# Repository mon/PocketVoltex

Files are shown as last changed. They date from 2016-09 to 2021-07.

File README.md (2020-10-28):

# Pocket Voltex

A tiny controller for K-Shoot MANIA/Sound Voltex or other similar games

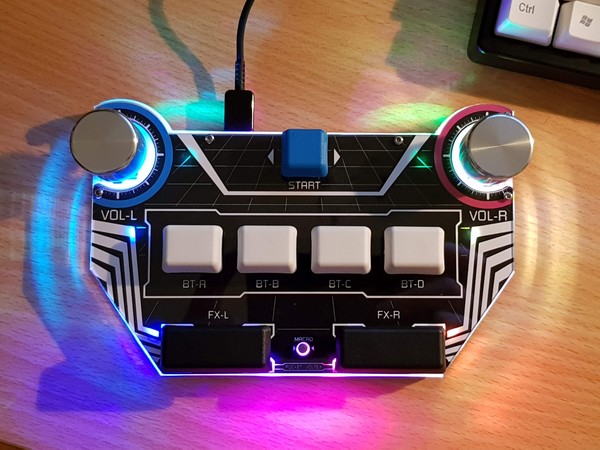
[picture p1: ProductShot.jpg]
Pocket Voltex


## Project status
There is a major revision coming sometime 2021 but I estimate requires 50+ hours
to complete design. It will significantly improve manufacturing efficiency and hopefully
allow me to sell controllers while working full-time.

Please don't hold your breath on a timely release, but I have not forgotten this
project.

## Documentation
[DIY Kit assembly](Docs/Assembly.md)  
[(Old version)DIY Kit assembly](Docs/Assembly_old.md)

[Controller configuration](Docs/Configuration.md)

## Features
* Gateron mechanical switches
* Rock solid Bourns encoders with hardware smoothing
* 8 RGB LEDs
* Beautiful laser cut acrylic case
* Custom aluminium knobs by DJ Dao
* Acts as a gamepad or keyboard/mouse (KSM)
* HID Lighting support
* Configurable card/pin macro key
* Chrome configurator
* No drivers required!

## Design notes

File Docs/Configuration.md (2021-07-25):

# Configuration

Configure your controller with the web app at:
https://mon.im/sdvx/config/

You will need Chrome 57+. You must be using SSL (https, not http).
You *might* also need to go to chrome://flags and enable
"Experimental Web Platform features". This step will not be required by
June/July, as the WebUSB feature will be shipping in Chrome 60.

If you are using b\*\*\*\*\*tools, configure as normal.
For fast configuration of the HID lighting, download and run [this exe](https://github.com/mon/PocketVoltex/raw/master/Software/HidLights.exe)
while config.exe is open and the controller is connected.

## KShootMania configuration
I recommend using the mouse+keyboard mode, as I have noticed slight jitter when using joystick mode - it appears to be caused when the knob rolls over from its maximum value to its minimum value. This also lets you bind START to the enter key, which lets you begin songs with the controller.

However, if you would like to use gamepad mode, simply bind the keys as normal (page 3 of the input selection) and select `Analog X/Y` as the knob input. I find sensitivity at 100 works best.

## NetworkError: Unable to claim interface.
This seems to be caused by broken drivers. Give Zadig a try!
- Download and run [Zadig](http://zadig.akeo.ie/)
- Click Options -> List All Devices
- Select 'Pocket Voltex Config' in the list
- Select WinUSB and click "Replace Driver"
- Config should now work!

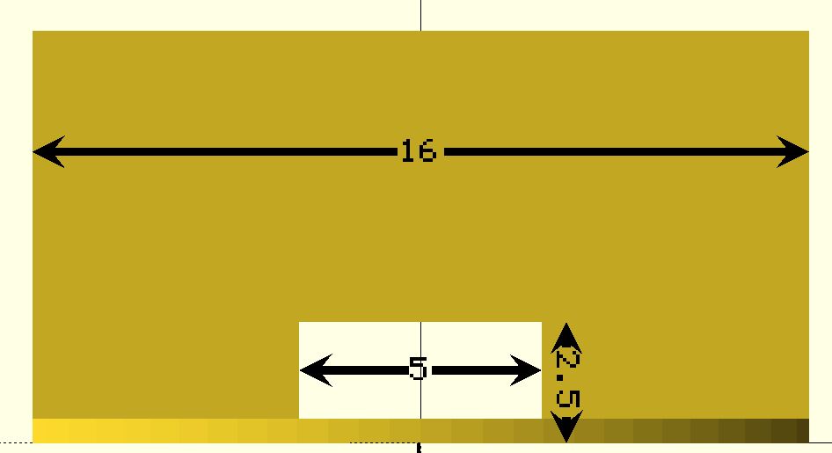
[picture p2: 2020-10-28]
Hardware/Encoder-holder/side.JPG

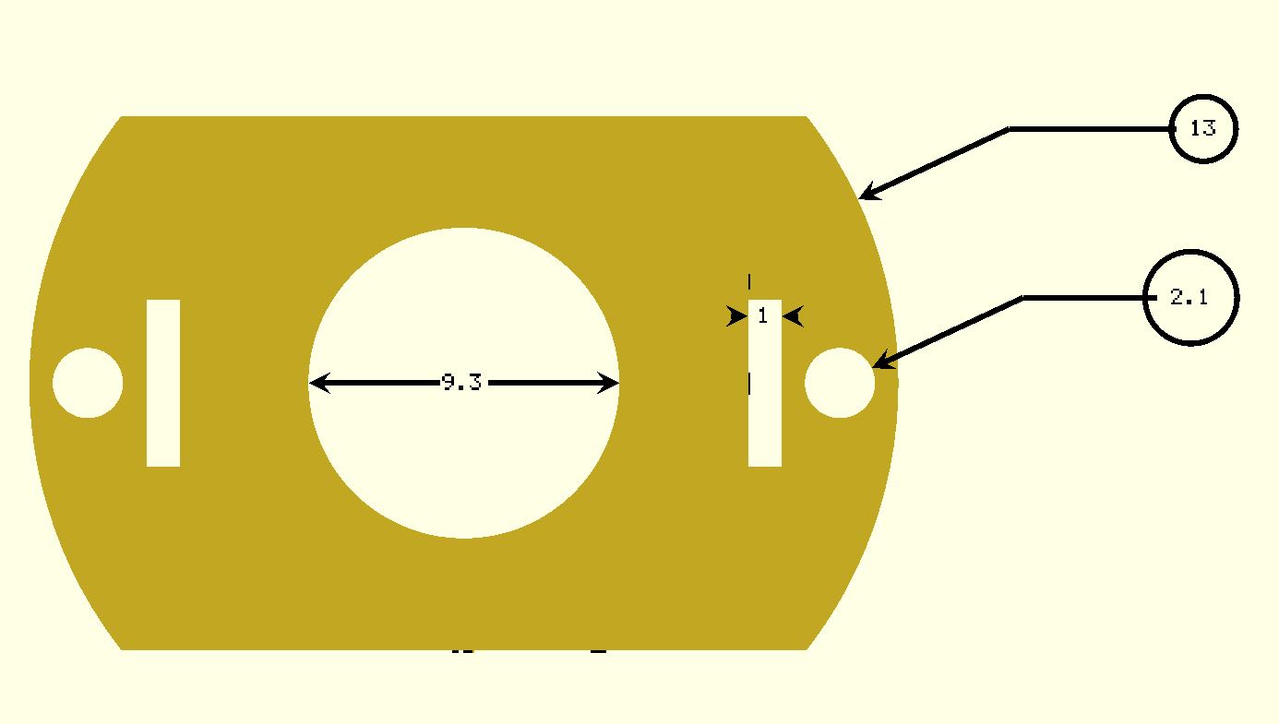
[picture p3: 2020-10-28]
Hardware/Encoder-holder/top.JPG

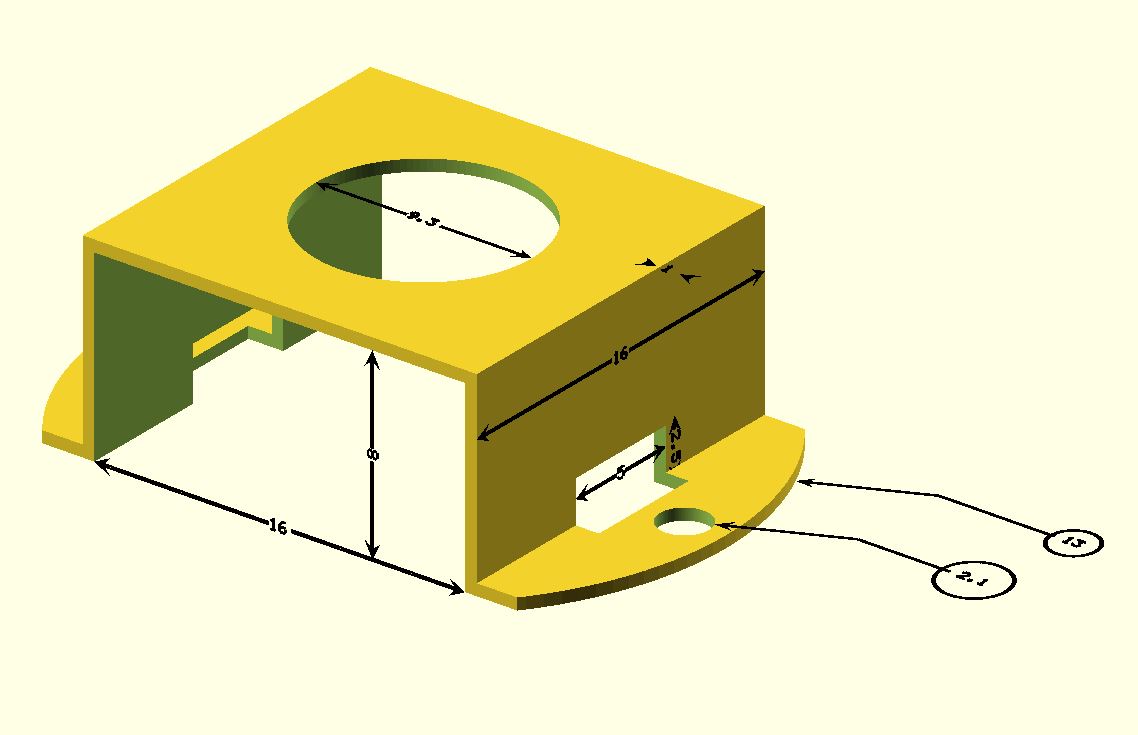
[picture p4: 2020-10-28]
Hardware/Encoder-holder/profile.JPG

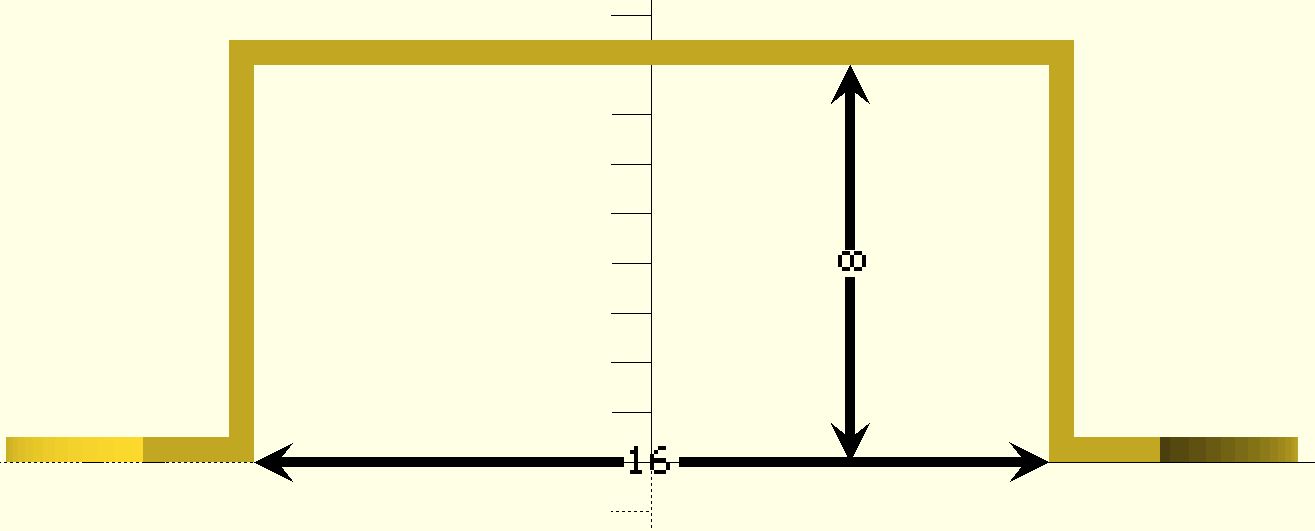
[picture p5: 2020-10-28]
Hardware/Encoder-holder/front.JPG

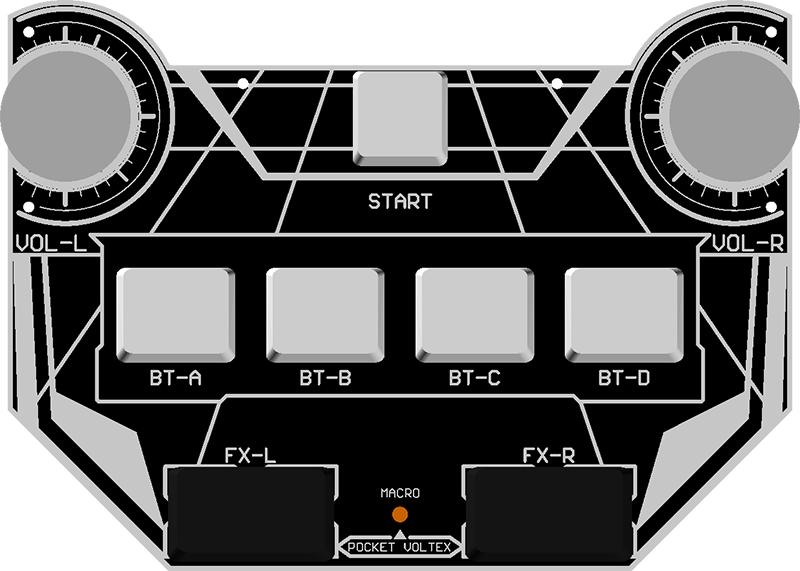
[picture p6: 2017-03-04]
Software/WebConfig/img/r4-topdown-small.png

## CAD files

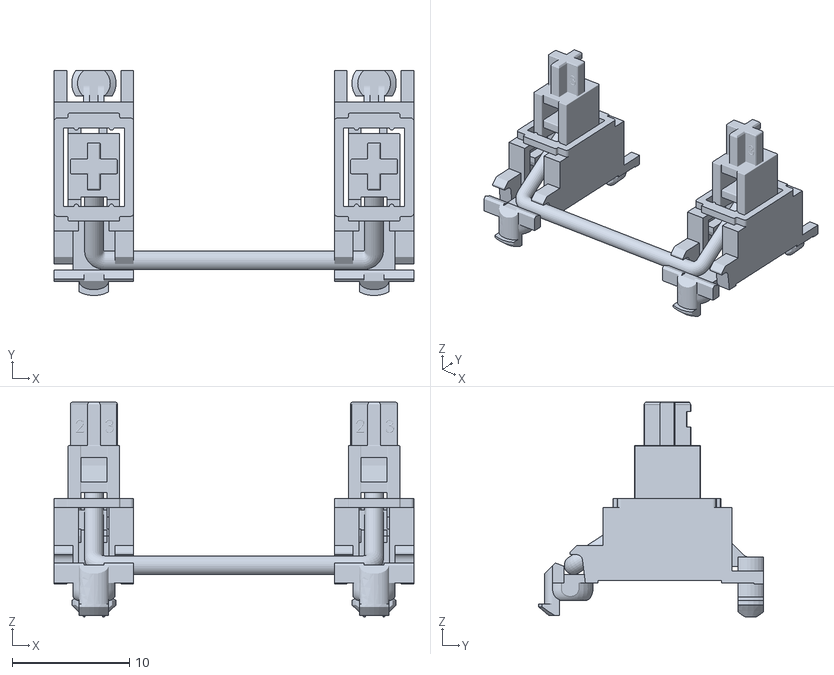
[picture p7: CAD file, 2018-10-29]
Hardware/Case/imports/mx_pcb_stab_open.stl
30.7 x 19.2 x 18.3

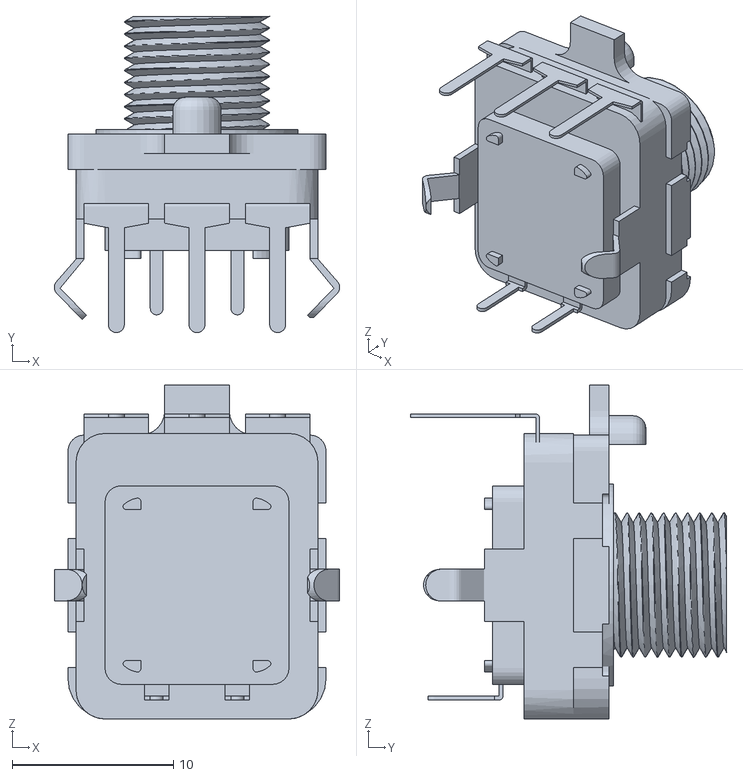
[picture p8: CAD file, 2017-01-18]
Hardware/Encoder-holder/imports/PEC16.stl
17.7 x 19.6 x 20.7

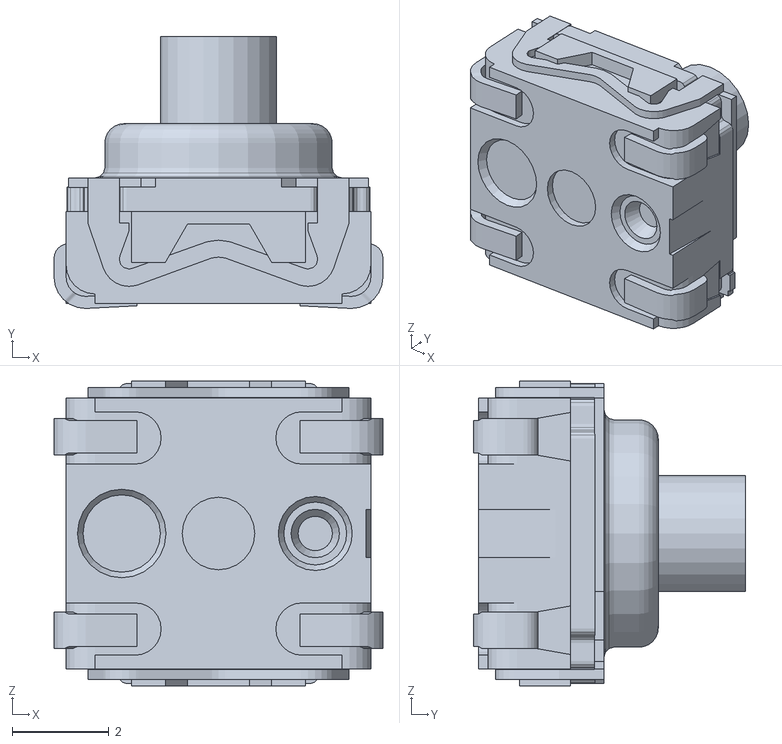
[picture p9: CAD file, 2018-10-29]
Hardware/Case/imports/KSC521J.stl
6.80 x 5.62 x 6.30

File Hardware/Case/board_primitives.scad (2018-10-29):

use <utils.scad>

black = [0.1,0.1,0.1];
blue = [0,0.6,1];
// x, y, keycap width in units, colour, text
bt_map = [[0,0, 1, blue, "START"],
           [-42.862,-37.592, 1.25, "white", "BT-A"],
           [ 42.862,-37.592, 1.25, "white", "BT-D"],
           [-14.287,-37.592, 1.25, "white", "BT-B"],
           [ 14.287,-37.592, 1.25, "white", "BT-C"]];
fx_map = [[-33.3375,-75.692, 2.25, black, "FX-L"],
           [ 33.3375,-75.692, 2.25, black, "FX-R"]];

bolt_map = [[37.4, 6.65],
         [80.5, -15.5],
         [80.5, 16.5],
         [52.732, -82.792]
         ];
encoder_map = [[-73,0.5],
            [ 73,0.5]];
// Not the encoders themselves, but the cutout that surrounds them
encoder_radius = 13;
// and for the board outline
encoder_radius_board = 22.222;

// encoder solder points hit the case unless we cut these out
// x, y, hole size
encoder_holes = [[-8, 0, 4],
                [ 8, 0, 4]];
// the 3 A/B/Gnd connections
// x (mirrored), y, hole size
encoder_hull = [5, -10.5, 3];

// x, y, rotation
led_map = [[47.1, -1.7, 0],
        [65, -30, 90],
        [57, -68, 45],
        [12, -80, 0]];
led_size = [7.5, 6.5];
                
macro_pos = [0,-75.692];
macro_diam = 4.8;

usb_dims = [11, 12];
usb_pos = [-26.52, 10.17];

// So you get a little clear acrylic edge and it looks nice
top_plate_shrink = 1;

fudge = 0.2;

bolt_diam = 2;
bolt_fudge = 0.1;
bolt_size = bolt_diam + bolt_fudge;
spacer_size = bolt_size + 1.7 + fudge; // extra wiggle

module bolts() {
    reflect([1,0,0])
    for(bolt = bolt_map) {
        translate(bolt)
        children();
    }
}

module bolts_external() {
    bolts()
    circle(d=bolt_size);
}

module bolts_internal() {
    bolts()
    circle(d=spacer_size);
}

module switches(map, apply_scaling, colour) {
    for(sw = map) {
        color(colour ? sw[3] : "gray")
        translate([sw.x,sw.y])
        scale([apply_scaling ? sw[2] : 1,1])
        children();
    }
}

module bt(apply_scaling = false, colour = true) {
    switches(bt_map, apply_scaling, colour)
        children();
}

module fx(apply_scaling = false, colour = true) {
    switches(fx_map, apply_scaling, colour)
        children();
}

module switches_all(apply_scaling = false, colour = true) {
    switches(fx_map, apply_scaling, colour)
        children();
    switches(bt_map, apply_scaling, colour)
        children();
}

module encoders() {
    for(enc = encoder_map) {
        translate(enc)
        children();
    }
}

module leds() {
    reflect([1,0,0])
    for(led = led_map) {
        translate([led.x, led.y])
        rotate([0,0,led[2]])
        children();
    }
}

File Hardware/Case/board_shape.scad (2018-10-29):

include <board_primitives.scad>
use <utils.scad>
use <cutouts.scad>

encoder_side_gap = 11;
function board_width() = (abs(encoder_map[0][0]) + encoder_side_gap)*2;

module board_half() {
    // 1mm gap for the important bits
    top_gap = 10.16;
    
    // arbitrary
    height = 96.64;
    angled_xoff = 55;
    
    // calculated
    width = board_width()/2;
    
    // main body
    translate([0, -height + top_gap])
    difference() {
        square([width, height]);
        
        translate([angled_xoff,0])
        rotate([0,0,-35])
        square([width, height]);
    }
    
    // encoder bits
    difference() {
        translate(encoder_map[1])
        circle(r=encoder_radius_board);
        
        translate([width, -height/2])
        square([width, height]);
    }
}

module board() {
    reflect([1,0,0])
    board_half();
}

module top_outline() {
    difference() {
        board();
        encoder_cutouts(smooth = true);
    }
}

board();

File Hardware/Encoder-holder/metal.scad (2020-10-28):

include <imports/dimlines.scad>
use <utils.scad>

$fn = 128;

// 0.2 a little less for tight hold
encoder = [16+0.2, 16, 6.5 - 0.2];
encoder_diam = 26;
side_cut = 0;
side_cut_height = 1.5;
side_cut_flat = 0.5;
hole_cut = 9.3;

material_thick = 0.8;

wing_rounding = 2;
hole_size = 2.1;
hole_clearance = 1.5;
hole_offset = [2.75+0.3,0,0];
wing_length = encoder.x*2; // will be trimmed

DIM_LINE_WIDTH = 0.17;
DIM_FONTSCALE = DIM_LINE_WIDTH * 0.4;

echo(wing_length);

module encoder_model() {
    translate([0,0,5.5])
    rotate([90,0,0])
    import("imports/PEC16.stl");
    
    // Shaft
    encoder_shaft = 6;
    encoder_flat = 4.5;
    translate([0,0,6.5])
    linear_extrude(20)
    intersection() {
        circle(d = encoder_shaft);
        translate([0, (encoder_shaft-encoder_flat)/2])
        square([encoder_shaft, encoder_flat], center = true);
    }
}

module xycube(dims) {
    translate([0,0,dims.z/2])
    cube(dims, center=true);
}

module main_bit() {
    intersection() {
        difference() {
            union() {
                xycube(encoder + [material_thick*2, 0, material_thick]);
                
                //color("green")
                xycube([
                    wing_length*2 + encoder.x + material_thick*2,
                    encoder.y,
                    material_thick
                ]);
            }
            // offsets are for nice f5 render
            translate([0,0,-1])
            xycube(encoder + [0,1,1]);
            
            // cutouts
            translate([0,0,-0.1])
            xycube([
                encoder.x+side_cut_flat*2+material_thick*2,
                side_cut,
                side_cut_height-0.1]);
            cylinder(d=hole_cut, h=encoder.z*2);
            
            screw_off = [
                hole_offset.x + encoder.x/2 - 0.2,
                hole_offset.y,
                0   
            ];
            echo("Screw offset from center", screw_off);
            // screws
            reflect([1,0,0])
            reflect([0,1,0])
            translate(screw_off + [0,0,-0.1])
            cylinder(d = hole_size, h = material_thick*2);
            
            
            reflect([1,0,0])
            reflect([0,1,0])
            translate(screw_off + [0,0,material_thick])
            #cylinder(d = 3.8, h = material_thick*2);
        }
        
        cylinder(d = encoder_diam, h = encoder.z*2);
    }
}

module dims() {
    translate([-encoder.x/2,-encoder.y/2,0])
    rotate([90,0,0])
    dimensions(encoder.x);
    
    translate([encoder.x/4,-encoder.y/2,encoder.z])
    rotate([90,90,0])
    dimensions(encoder.z);
    
    translate([encoder.x/2+material_thick,-encoder.y/2,6])
    rotate([90,0,90])
    dimensions(encoder.y);
    
    translate([encoder.x/2+material_thick,-side_cut/2,1.5])
    rotate([90,0,90])
    dimensions(side_cut);
    
    translate([encoder.x/2+material_thick,side_cut/2+0.5,side_cut_height])
    rotate([90,90,90])
    dimensions(side_cut_height);
    
    translate([-hole_cut/2,0,encoder.z+material_thick])
    dimensions(hole_cut);
    
    leader_line(25, encoder_diam/2, 5, 5, text = str(encoder_diam), do_circle=true);
    
    screw_off = [
        hole_offset.x + encoder.x/2 + material_thick,
        hole_offset.y,
        0   
    ];
    
    translate(screw_off + [0,0,material_thick])
    leader_line(25, hole_size/2, 5, 4, text = str(hole_size), do_circle=true);
    
    translate([encoder.x/2 + material_thick,2,material_thick+encoder.z+0.1])
    dimensions(side_cut_flat, loc = DIM_OUTSIDE);
}

//color("gray")
//encoder_model();

//color("black")
//dims();

main_bit();

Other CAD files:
Hardware/Encoder-holder/utils.scad
Hardware/Case/artwork.scad
Hardware/Case/box.scad
Hardware/Case/case.scad
Hardware/Case/cutouts.scad
Hardware/Case/imports/cherry_mx.scad
Hardware/Case/imports/mx_keycap.scad
Hardware/Case/utils.scad
Hardware/Encoder-holder/imports/TextGenerator.scad
Hardware/Encoder-holder/imports/dimlines.scad

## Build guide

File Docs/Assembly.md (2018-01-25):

# Assembly
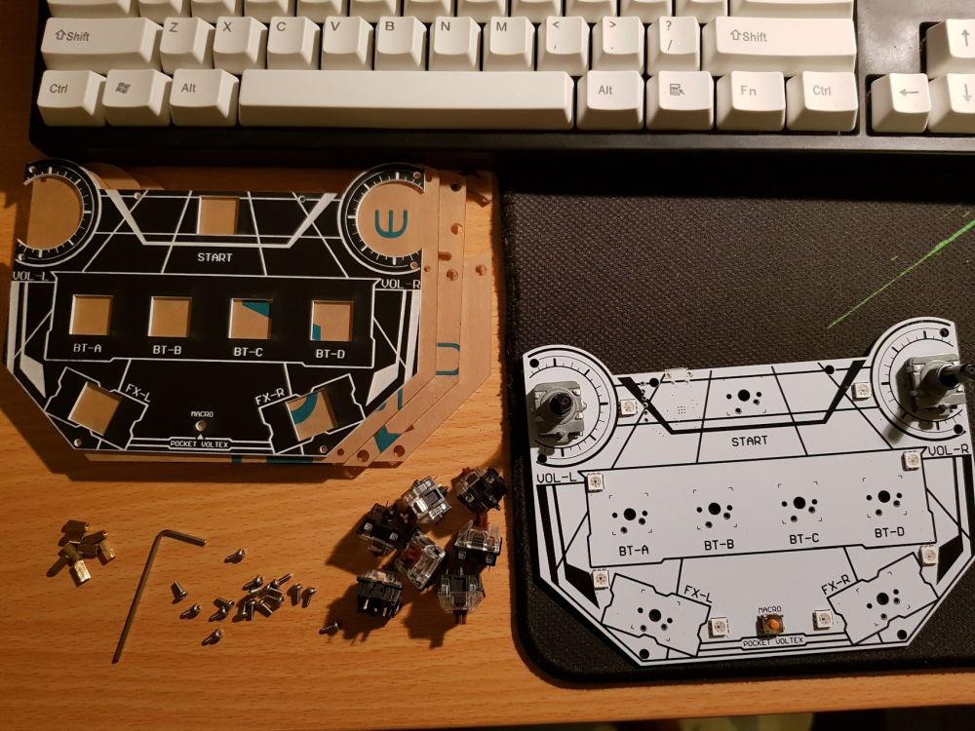
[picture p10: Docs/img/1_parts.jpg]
parts


Run through this guide once before building, ensuring you have all the parts required. You'll also need a soldering iron and solder.

## Acrylic
**STOP NOW!** I *know* it's tempting, but don't peel off the protective backing from all the acrylic yet.
Once it's off, the pieces attract dust, which can make the rear look messy.

**WARNING:** The top 2 plates (those with encoder holes) are fragile and easily snap if dropped. Take care when assembling. Once assembled, they are protected by the rest of the controller and should not break.

Take off the protective backing from the top clear acrylic.
Take your top clear plate and top black plate and place them over the LEDs. Take note of the clear plate - it has engraved edges for optimal lighting. It can be installed with the edges up or down, but they look best when facing up.
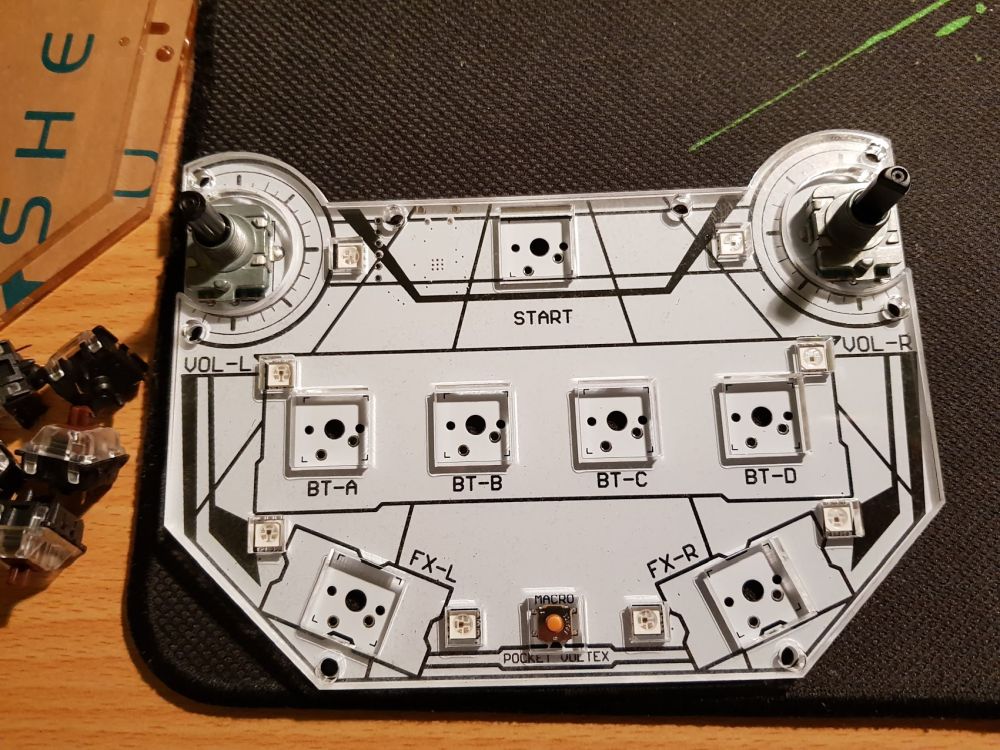
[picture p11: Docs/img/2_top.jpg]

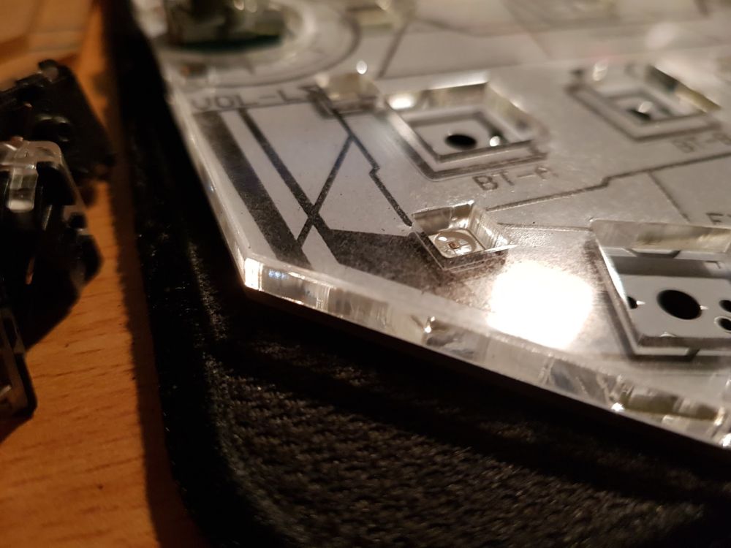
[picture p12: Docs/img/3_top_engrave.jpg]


Use the 1.5mm Allen key provided to screw the board together.
Insert the top 8 bolts and 8 long nuts into the holes provided.
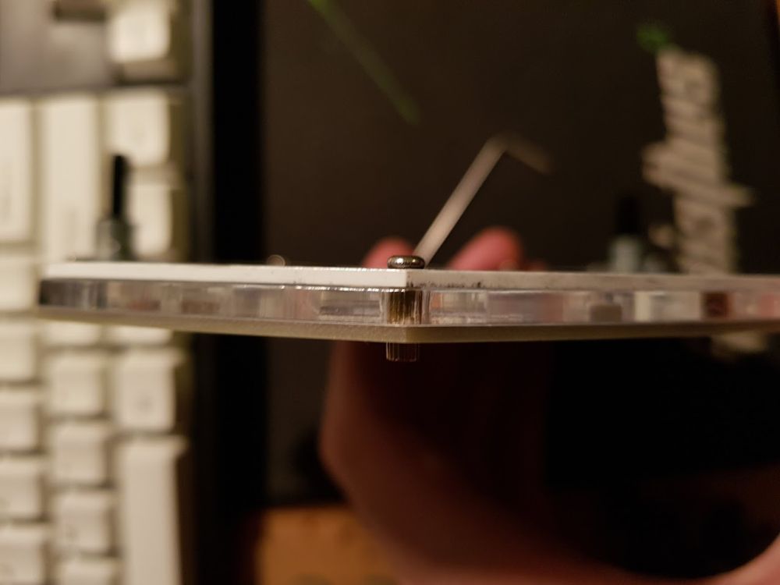
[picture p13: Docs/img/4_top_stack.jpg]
nutsNbolts


## Switches
Insert all your switches, and make sure they are seated properly. They are meant to be a tight fit into the PCB and should be completely flush with the surface.
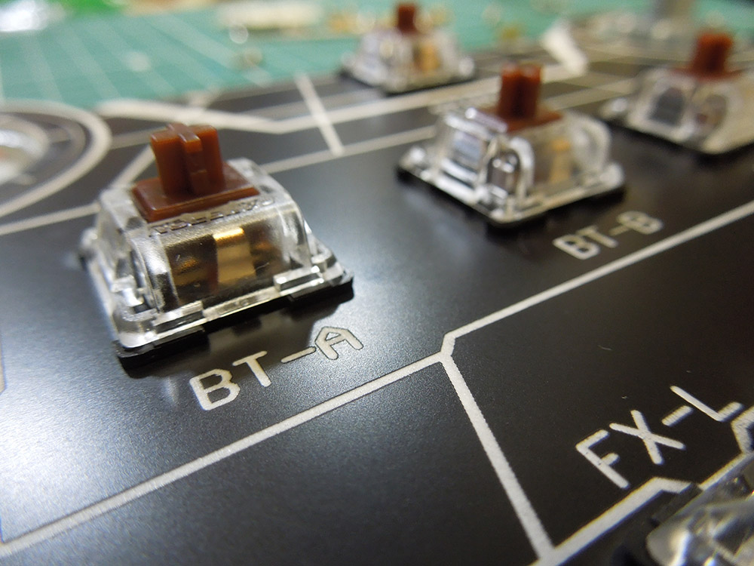
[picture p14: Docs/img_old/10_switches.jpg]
switches


Solder the switches. I solder with the back plate on, with its protective backing. This prevents flux from splashing over your board.
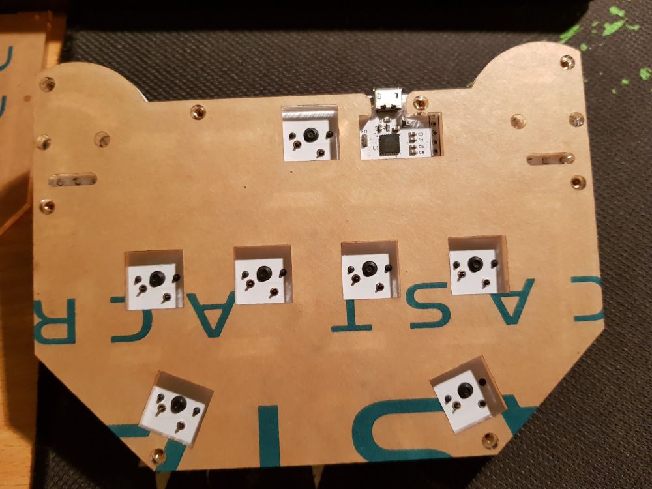
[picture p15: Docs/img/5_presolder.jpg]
protec


## Nuts and bolts
Stack the bottom 2 plates after removing their protective backing and insert the remaining 8 bolts.
Take care to align the cutout over the USB port.
Attach your 6 adhesive rubber feet. You can place these anywhere, but here is where I put them:
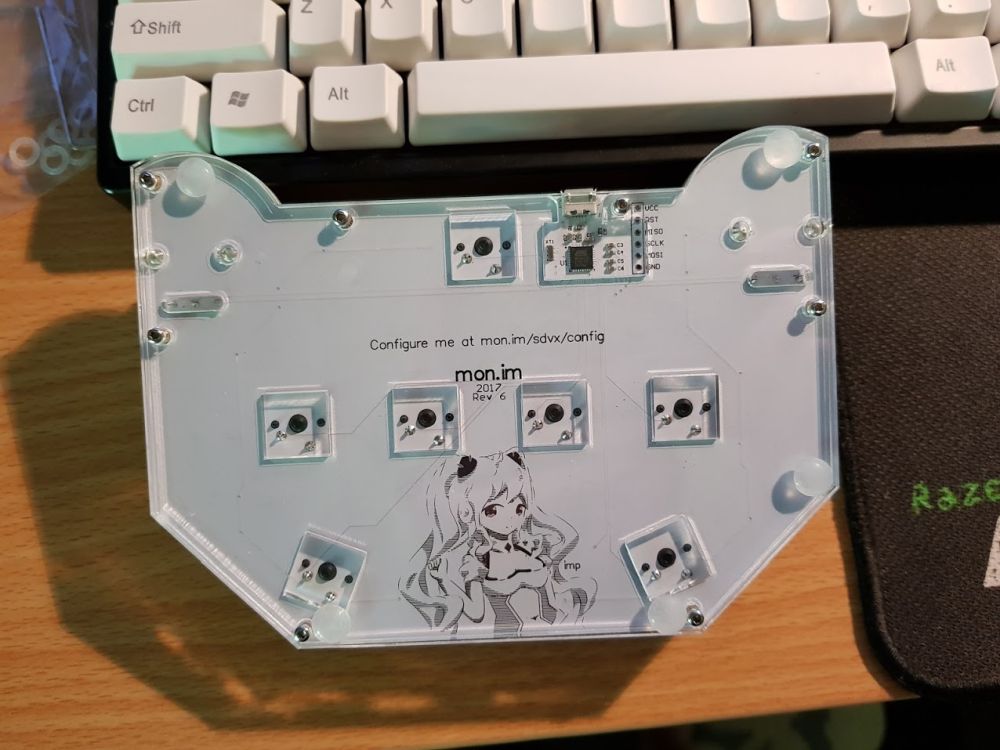
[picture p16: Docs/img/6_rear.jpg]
acrylicDone


# Final touches
Using the Allen key provided, attach the knobs. The encoder shaft is shaped like a D - ensure you tighten the grub screw on the flat part of the D.

*Optional:* Add 7 o-rings to your keycaps to make them quieter.

Install keycaps by simply pushing them onto the switches.

done

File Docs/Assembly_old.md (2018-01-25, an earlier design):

# Assembly
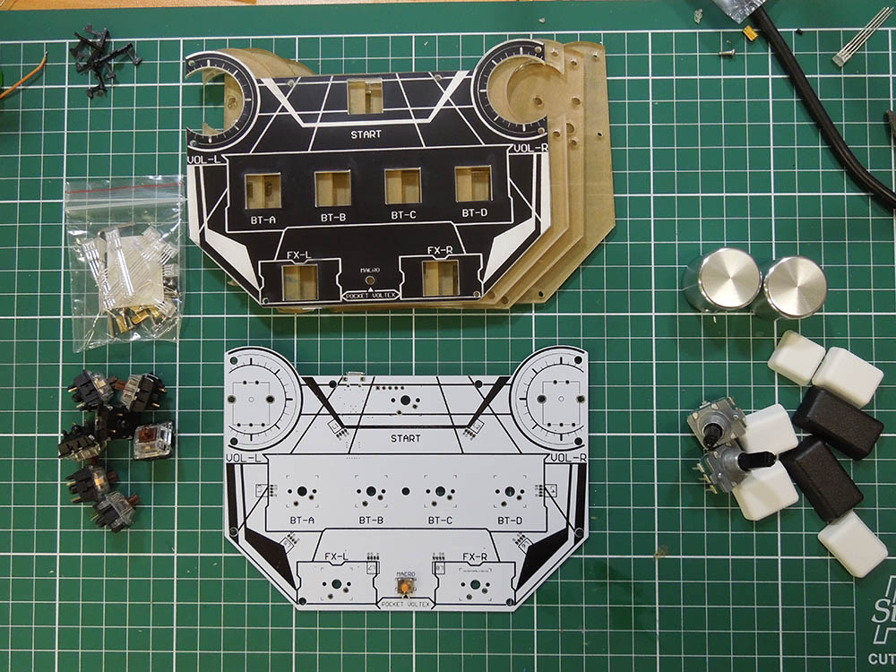
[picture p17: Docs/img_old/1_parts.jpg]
parts


Run through this guide once before building, ensuring you have all the parts required. You'll also need a soldering iron and solder.

## LEDs
First up, the LEDs.

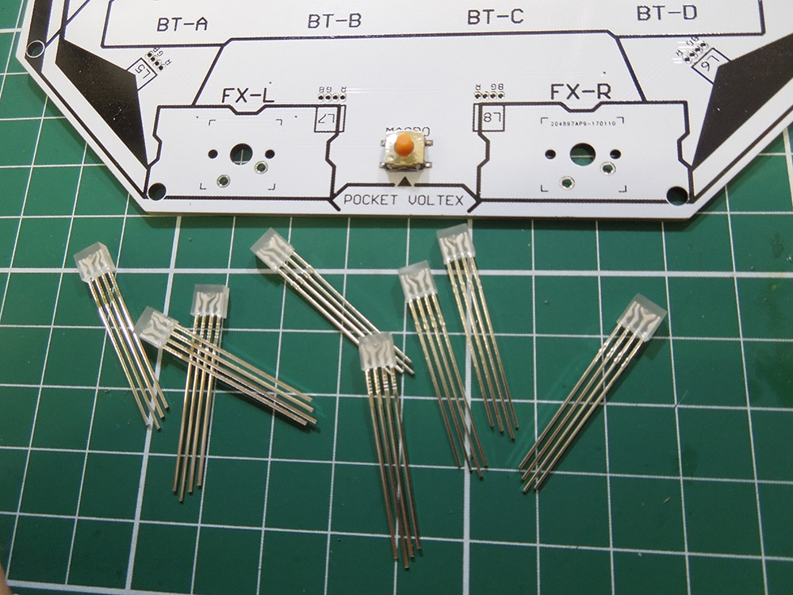
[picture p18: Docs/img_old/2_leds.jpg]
leds


Take note, each LED point on the board has labelled connections for R, G and B. The long leg on the LEDs goes into the unmarked (ground) hole.

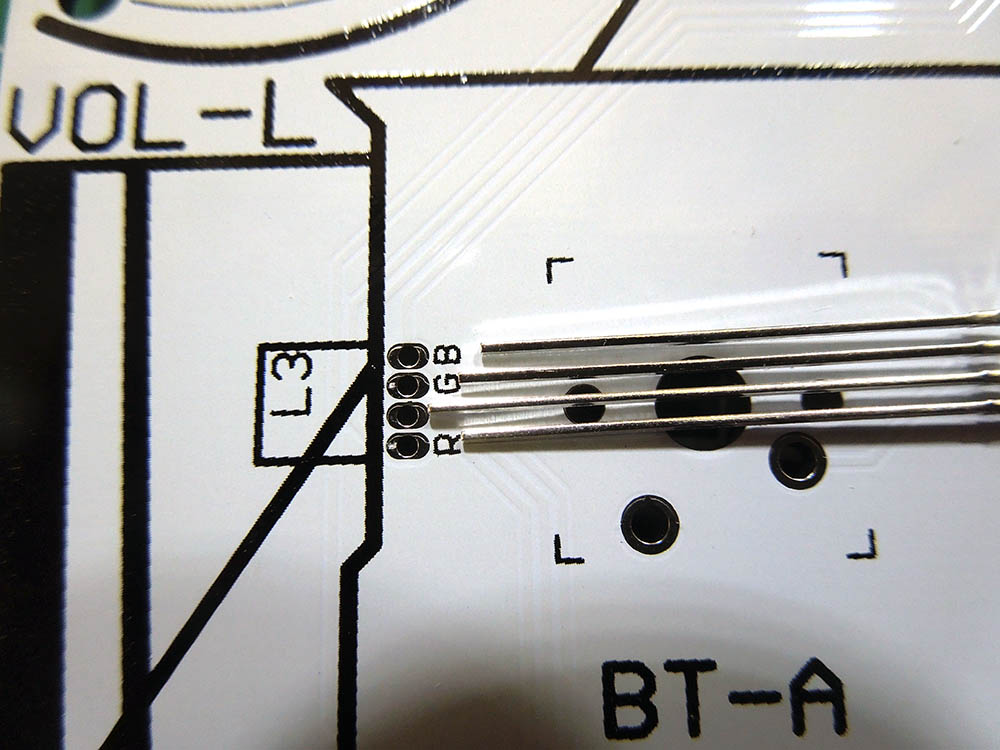
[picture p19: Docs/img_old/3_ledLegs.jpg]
ledLegs


Insert the LEDs roughly to the red line, then bend them over:
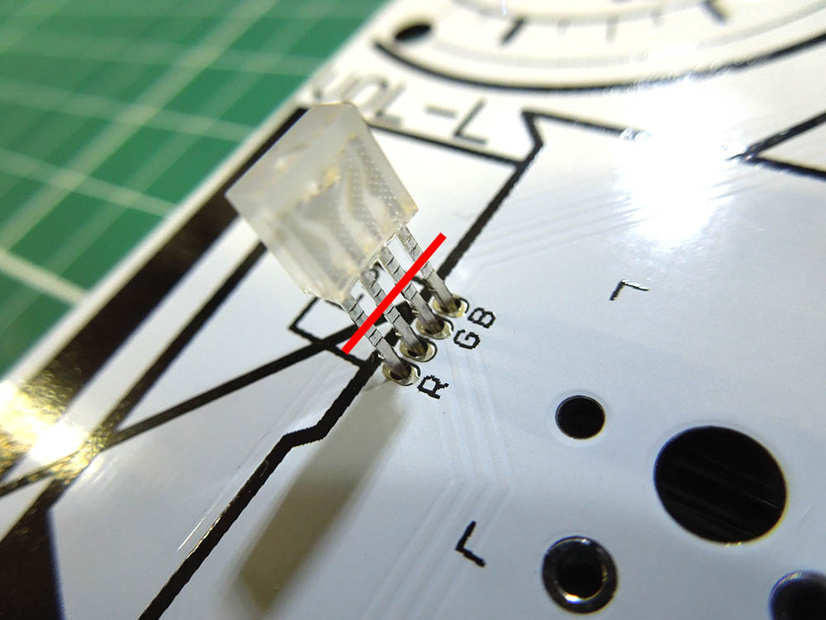
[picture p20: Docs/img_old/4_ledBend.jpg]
ledBend

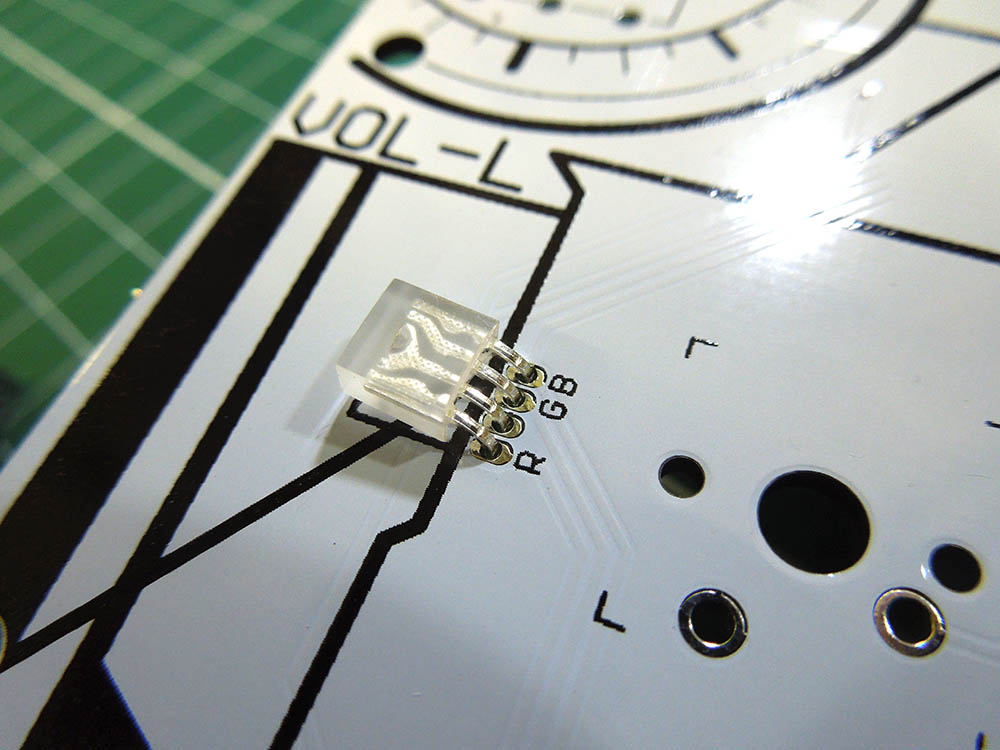
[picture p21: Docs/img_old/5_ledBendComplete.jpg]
ledBendComplete


Work on a slightly raised surface and place the board face down to solder, with the MACRO switch off the edge. This ensures all the LEDs are flush with the board surface.
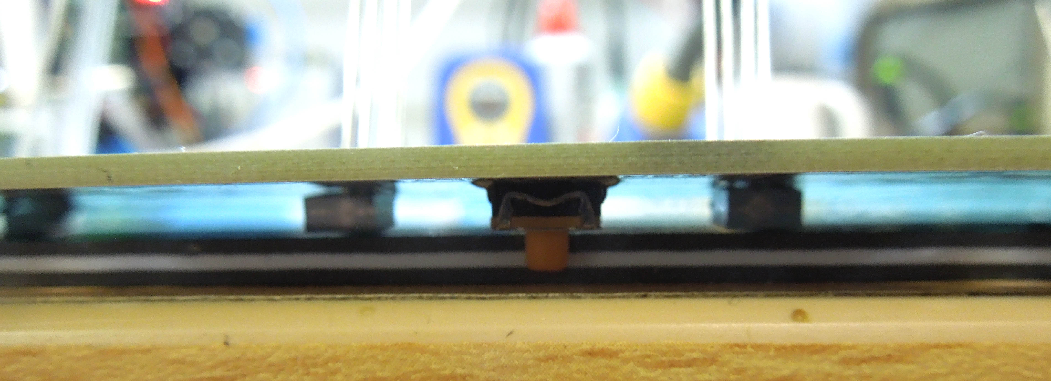
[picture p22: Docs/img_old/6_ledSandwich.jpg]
ledSandwich


I recommend soldering one leg of each LED to keep it in place, then cutting off all the leads. This makes soldering the rest of the connections much easier.

The bend doesn't have to be perfect - the acrylic will diffuse the light.
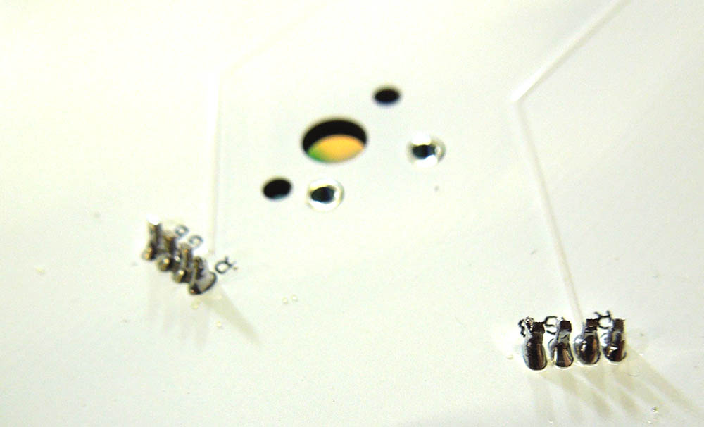
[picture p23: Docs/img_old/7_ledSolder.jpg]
ledSolder


## Encoders
You can solder the encoders now or after you install the switches, but I prefer to do them sooner. Solder one of the small pins to keep it in place then pump lots of solder into the big connecting lugs. These need to take your abuse, so make it a good joint!
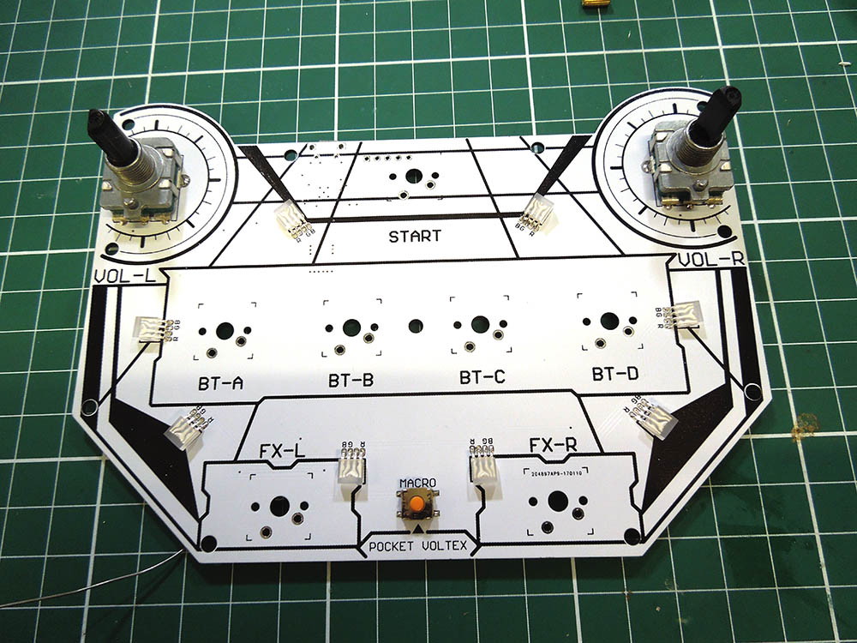
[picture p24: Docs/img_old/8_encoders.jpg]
encoders


## Switches
**STOP NOW!** Have you finished soldering your LEDs? Have you tested them?
Once you have soldered the switches you cannot fix anything without desoldering
them again.

**WARNING:** The top 2 plates (those with encoder holes) are fragile and easily snap if dropped. Take care when assembling. Once assembled, they are protected by the rest of the controller and are much stronger.

Take your top clear plate and top black plate and place them over the LEDs. Take note of the clear plate - it has engraved edges for optimal lighting. It can be installed with the edges up or down, but they look best when facing up.
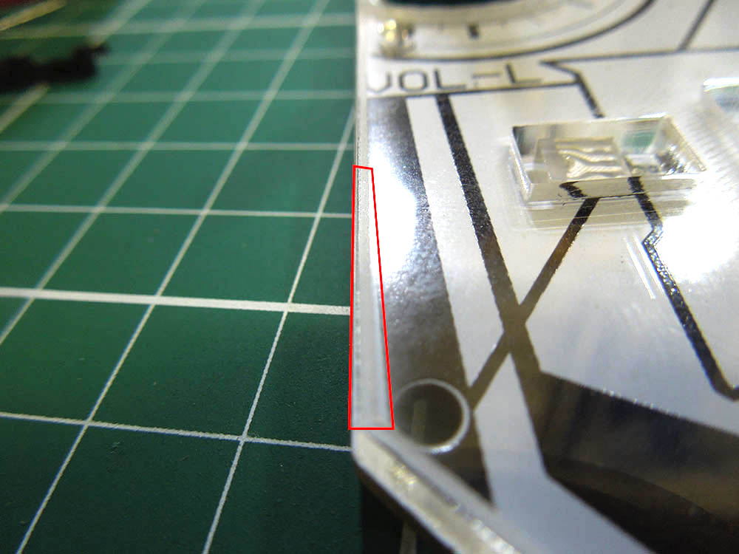
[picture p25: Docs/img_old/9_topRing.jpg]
topRing


Insert all your switches, and make sure they are seated properly. They are meant to be a tight fit into the PCB and should be completely flush with the surface.
switches

## Nuts and bolts
Use the 1.5mm Allen key provided to screw the board together.
Insert the top 8 bolts and 8 long nuts into the holes provided. Take note, there are 3 holes in the PCB that are unused. These nuts can sometimes be a tight fit - you may need to push them into the case with a hard surface.
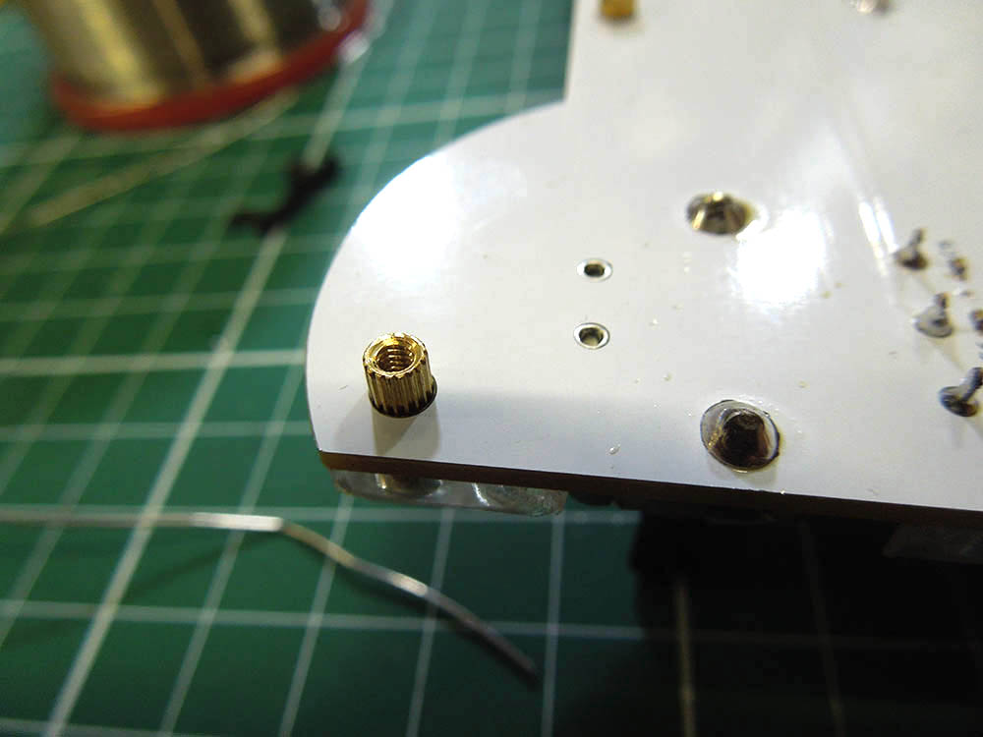
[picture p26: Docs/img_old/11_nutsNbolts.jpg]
nutsNbolts


Stack the bottom 2 plates and insert the remaining 8 bolts. Take care to align the cutout over the USB port. The bolts are a fraction too short, you may need to back off the top bolts by about 2 turns to get the nut close enough.
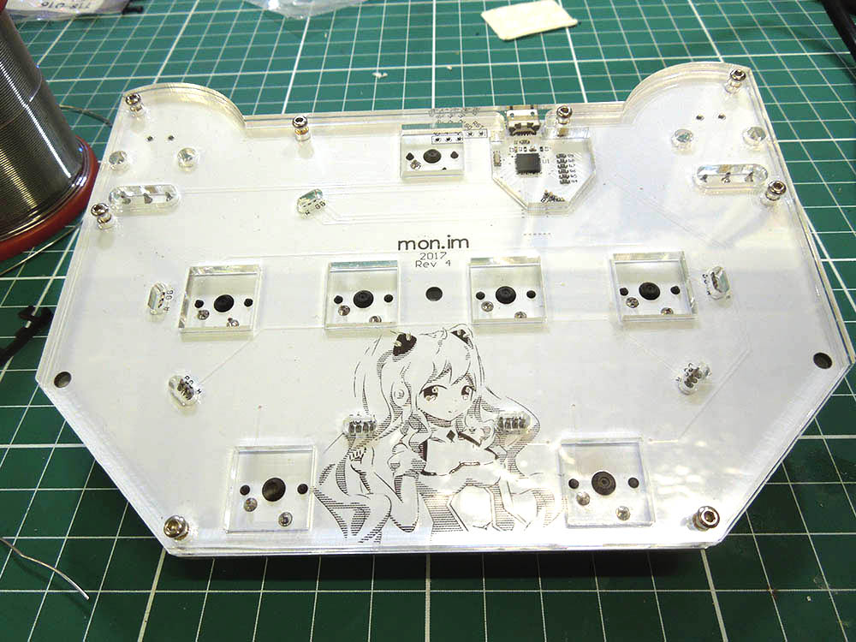
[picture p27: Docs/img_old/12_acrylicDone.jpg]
acrylicDone


## Rubber feet
Attach your 6 adhesive rubber feet. You can place these anywhere, but here is where I put them:
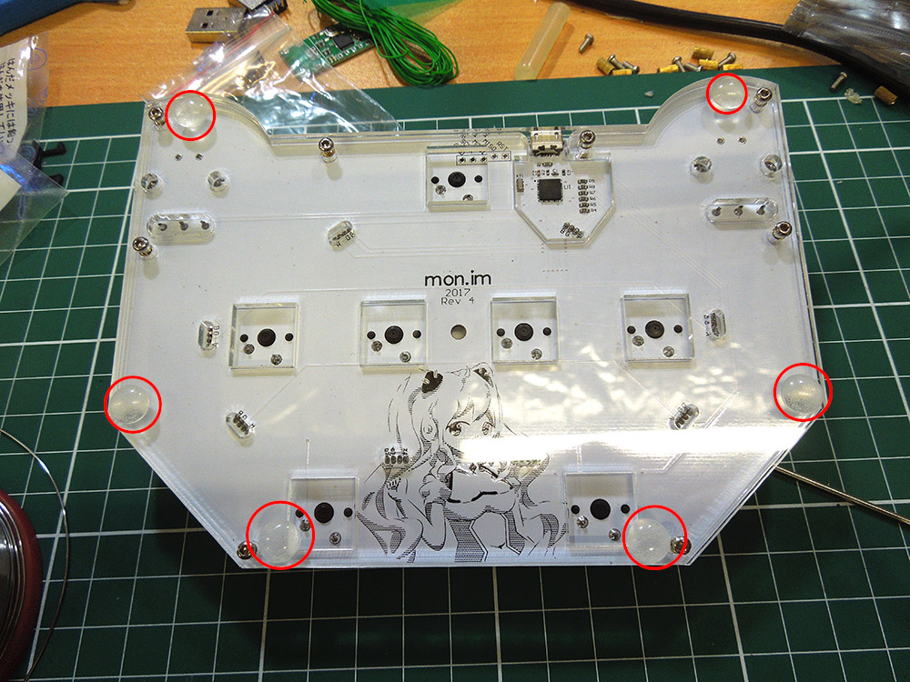
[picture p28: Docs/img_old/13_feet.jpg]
feet


# Final touches
Using the Allen key provided, attach the knobs. The encoder shaft is shaped like a D - ensure you tighten the grub screw on the flat part of the D.

*Optional:* Add 7 o-rings to your keycaps.

Install keycaps by simply pushing them onto the switches.

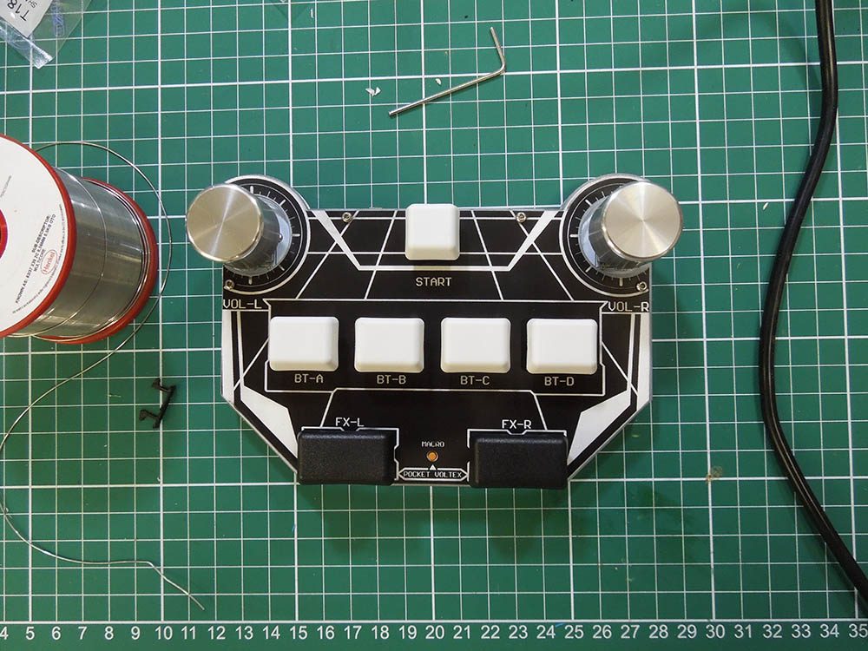
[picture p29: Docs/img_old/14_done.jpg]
done


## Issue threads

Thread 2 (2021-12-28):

PocketVoltex with ProMicro

Katsuyuki-Karasawa, 2021-12-28:
This keyboard is very practical (especially in Japan, where there is a definite demand for it), and since there is an actual store in Japan related to homemade keyboards called Yusha Kobo, we'd really like to see it supported!

mon, 2021-12-29:
I've been to that store! Such a wonderful place.

I'm a little confused as to the request, though. What are you proposing?
- Pocket Voltex with socket/connectors for Pro Micro
- Pocket Voltex that supports using the Arduino Bootloader (atmega32u4 and correct pinout)

I am currently designing a new version that uses the 32u2 (note: u2 not u4, less pins) which can use an arduino core I think, I haven't checked. It will also have a plastic case, so it's taking a bit of time.

I think, for a more DIY friendly Pocket Voltex you might want to look at https://github.com/speedypotato/Pocket-SDVX
It uses a Pro Micro already! And uses a 3D printed case. It's very maker-friendly ^_^

Closed 2022-01-02.

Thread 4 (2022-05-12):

about fireware

HHHHHWTF, 2022-05-12:
When I download LUFA170418 and copy LUFA file folder and run a .bat file name multiflasher from PocketVoltex on Firmware,I get some code:
      0 [main] sh 10300 sync_with_child: child 18804(0x1E0) died before initialization with status code 0xC0000142
    158 [main] sh 10300 sync_with_child: *** child state waiting for longjmp
/usr/bin/sh: fork: Resource temporarily unavailable
      0 [main] sh 9252 sync_with_child: child 1840(0x1EC) died before initialization with status code 0xC0000142
    119 [main] sh 9252 sync_with_child: *** child state waiting for longjmp
/usr/bin/sh: fork: Resource temporarily unavailable
      0 [main] sh 19276 sync_with_child: child 14104(0x1EC) died before initialization with status code 0xC0000142
    223 [main] sh 19276 sync_with_child: *** child state waiting for longjmp
/usr/bin/sh: fork: Resource temporarily unavailable
 [GCC]     : Compiling C file "PocketVoltex.c"
avr-gcc -c -pipe -gdwarf-2 -g2 -mmcu=atmega16u2 -fshort-enums -fno-inline-small-functions -fpack-struct -Wall -fno-strict-aliasing -funsigned-char -funsigned-bitfields -ffunction-sections -I. -DARCH=ARCH_AVR8 -DF_CPU=16000000UL -mrelax -fno-jump-tables -x c -Os -std=gnu99 -Wstrict-prototypes -DUSE_LUFA_CONFIG_HEADER -IConfig/ -Werror  -I. -I../LUFA/.. -DARCH=ARCH_AVR8 -DBOARD=BOARD_USER -DF_USB=16000000UL  -MMD -MP -MF obj/PocketVoltex.d PocketVoltex.c -o obj/PocketVoltex.o
Assembler messages:
Fatal error: can't create obj/PocketVoltex.o: No such file or directory
How can I deal with this problem?

mon, 2022-05-20:
I know you closed this issue, but I just uploaded EVERY manufacturing file:
https://github.com/mon/PocketVoltex/releases/tag/rev7

Good luck! Please email me if you have success.

Closed 2022-05-18.

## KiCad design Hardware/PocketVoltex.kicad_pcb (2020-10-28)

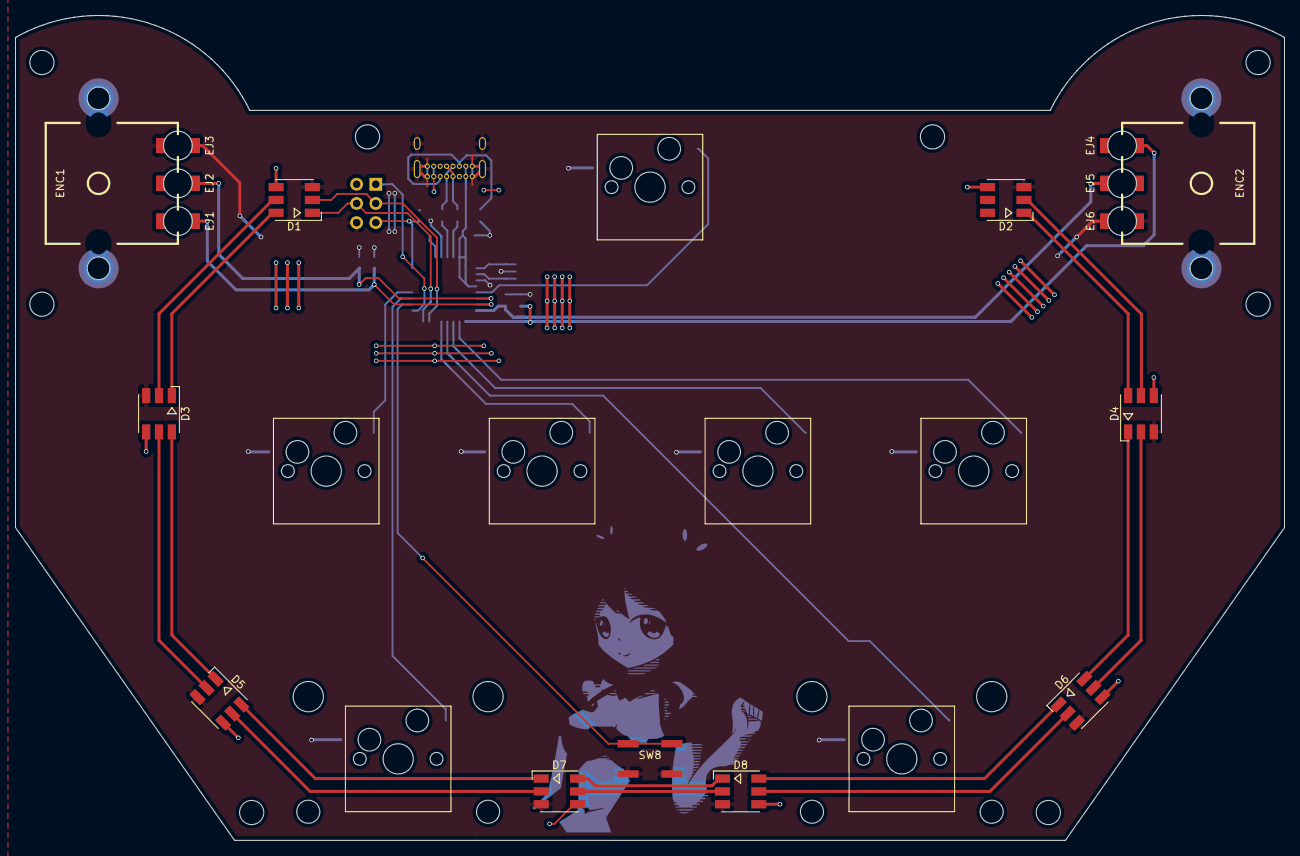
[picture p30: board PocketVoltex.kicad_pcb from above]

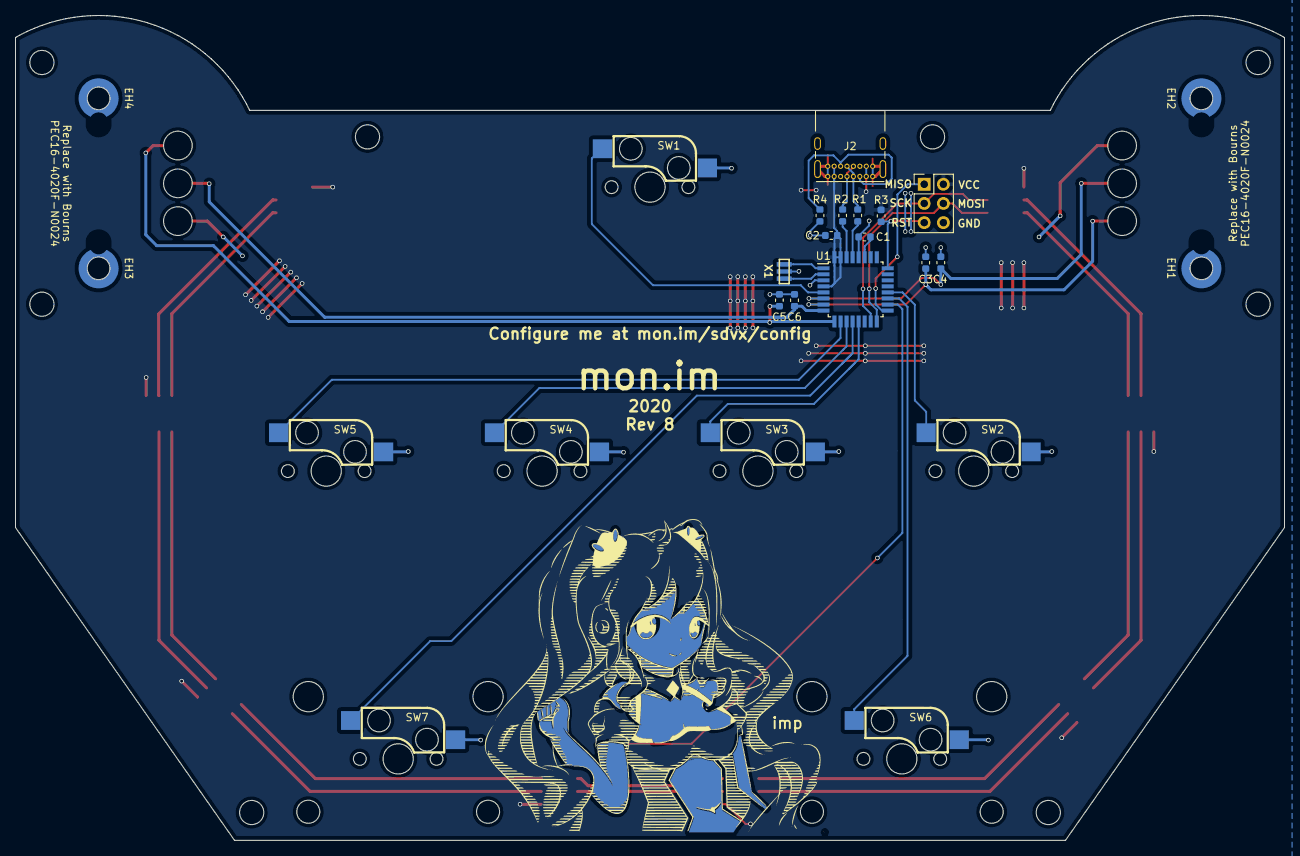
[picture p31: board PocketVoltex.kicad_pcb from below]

Board: 2 copper layers, 168.0 x 109.2 mm, 51 parts (19 on the bottom side), 40 nets.

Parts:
C1: 1uF; C_0603_1608Metric
C2: 10uF; C_0603_1608Metric
C3, C4, C5, C6: 10nF; C_0603_1608Metric
D1, D2, D3, D4, D5, D6, D7, D8: SK9822; LED_SK9822
EH1, EH2, EH3, EH4: Encoder nut; SMD_Standoff_M2_Wurth
EJ1, EJ2, EJ3, EJ4, EJ5, EJ6: Hotswap; Harwin-SMD-Socket-S9091-46R
ENC1: VOL_L; Encoder_Bourns_PEC16_hotswap
ENC2: VOL_R; Encoder_Bourns_PEC16_hotswap
H1, H2, H3, H4, H5, H6, H7, H8: MountingHole; MountingHole_3.2mm_M3
J1: Programming header; PinHeader_2x03_P2.54mm_Vertical
J2: USB_C_Receptacle; USB_C_Receptacle_GCT_USB4085
LOGO1: Rasis
R1, R2: 22R; R_0603_1608Metric
R3: 10k; R_0603_1608Metric
R4: 5.1k; R_0603_1608Metric
SW1: MX socket; SW_Cherry_MX1A_1.00u_PCB_Socket
SW2, SW3, SW4, SW5: MX socket; SW_Cherry_MX1A_1.25u_PCB_Socket
SW6, SW7: MX socket; SW_Cherry_MX1A_2.25u_PCB_Socket
SW8: SW_Push; SW_SPST_KSC-J
U1: ATmega32U2-AU; TQFP-32_7x7mm_P0.8mm
X1: 16MHz; murata-resonator_SMD_CSTCE16M0V53-R0

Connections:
/D+: J2.A6, J2.B6, R1.1
/D-: J2.A7, J2.B7, R2.2
/ENC1A: C3.1, EJ1.1, ENC1.A, U1.7
/ENC1B: C4.2, EJ2.1, ENC1.B, U1.6
/ENC2A: C5.1, EJ4.1, ENC2.A, U1.9
/ENC2B: C6.2, EJ5.1, ENC2.B, U1.8
/MISO: J1.1, U1.17
/MOSI: D1.1, J1.4, U1.16
/RESET: J1.5, R3.2, U1.24
/SCLK: D1.2, J1.3, U1.15
/SW_A: SW2.1, U1.20
/SW_B: SW3.1, U1.13
/SW_C: SW4.1, U1.11
/SW_D: SW5.1, U1.10
/SW_FXL: SW6.1, U1.19
/SW_FXR: SW7.1, U1.12
/SW_MACRO: SW8.1, U1.18
/SW_START: SW1.1, U1.5
GND: C1.1, C2.2, C3.2, C4.1, C5.2, C6.1, D1.3, D2.3, D3.3, D4.3, D5.3, D6.3, D7.3, D8.3, EJ3.1, EJ6.1, ENC1.C, ENC2.C, J1.6, J2.A1, J2.A12, J2.B1, J2.B12, J2.S1, R4.1, SW1.2, SW2.2, SW3.2, SW4.2, SW5.2, SW6.2, SW7.2, SW8.2, U1.3, U1.28, X1.2
unnamed: C1.2, U1.27
unnamed: D1.5, D3.2
unnamed: D1.6, D3.1
unnamed: D2.1, D4.6
unnamed: D2.2, D4.5
unnamed: D3.5, D5.2
unnamed: D3.6, D5.1
unnamed: D4.1, D6.6
unnamed: D4.2, D6.5
unnamed: D5.5, D7.2
unnamed: D5.6, D7.1
unnamed: D6.1, D8.6
unnamed: D6.2, D8.5
unnamed: D7.5, D8.2
unnamed: D7.6, D8.1
unnamed: J2.A5, J2.B5, R4.2
unnamed: R1.2, U1.29
unnamed: R2.1, U1.30
unnamed: U1.1, X1.1
unnamed: U1.2, X1.3
VCC: C2.1, D1.4, D2.4, D3.4, D4.4, D5.4, D6.4, D7.4, D8.4, J1.2, J2.A4, J2.A9, J2.B4, J2.B9, R3.1, U1.4, U1.31, U1.32

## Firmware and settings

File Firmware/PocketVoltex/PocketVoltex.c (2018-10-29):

#include "PocketVoltex.h"
#include "Config.h"
#include "Encoder.h"
#include "LED.h"
#include "LEDPatterns.h"
#include "Macro.h"

#define LOAD_SWITCH(source, sourceBit, result, resultBit) result |= !((source) & _BV(sourceBit)) << resultBit

#ifdef SOFT_LEDS
    // B 0,1
    #define SWITCH_MASKB 0b00000011
    // C 1,2
    #define SWITCH_MASKC 0b00000110
    // D 4,5,6,7
    #define SWITCH_MASKD 0b11110000
#else
    // B 4,5,6
    #define SWITCH_MASKB 0b01110000
    // C 2
    #define SWITCH_MASKC 0b00000100
    // D 4,5,6,7
    #define SWITCH_MASKD 0b11110000
#endif

// How long to wait before moving to internal lighting
#define HID_LED_TIMEOUT 2000

// If I add more buttons with the macro key I don't need to care
#if SWITCH_COUNT <= 8
    #define SWITCH_BITMASK_UINT uint8_t
#elif SWITCH_COUNT <= 16
    #define SWITCH_BITMASK_UINT uint16_t
#else
    #error TOO MANY SWITCHES
#endif
typedef struct
{
    int8_t  X; // VOL-L
    int8_t  Y; // VOL-R
    SWITCH_BITMASK_UINT Buttons; // bitmask
} Joystick_Report_t;

typedef struct
{
    uint8_t Modifier; // Keyboard modifier byte indicating pressed modifier keys (\c HID_KEYBOARD_MODIFER_* masks)
    uint8_t Reserved; // Reserved for OEM use, always set to 0.
    uint8_t KeyCode[SWITCH_COUNT]; // Length determined by the number of keys that can be reported
} Keyboard_Report_t;

typedef struct
{
    uint8_t mainLights[LED_PHYSICAL_COUNT];
    uint8_t btFx[6];
} LED_Report_t;

static uint8_t sendKeyboard = 0;
static uint8_t updateLEDs = 1;
static int8_t joystickKnobs[2] = {0, 0};

/** LUFA HID Class driver interface configuration and state information. This structure is
 *  passed to all HID Class driver functions, so that multiple instances of the same class
 *  within a device can be differentiated from one another.
 */
USB_ClassInfo_HID_Device_t Inputs_HID_Interface =
{
    .Config =
        {
            .InterfaceNumber              = INTERFACE_ID_Inputs,
            .ReportINEndpoint             =
                {
                    .Address              = INPUTS_EPADDR,
                    .Size                 = INPUTS_EPSIZE,
                    .Banks                = 1,
                },
            .PrevReportINBuffer           = NULL,
            .PrevReportINBufferSize       = MAX(MAX(sizeof(Keyboard_Report_t), sizeof(Joystick_Report_t)), sizeof(USB_MouseReport_Data_t)),
        },
};

USB_ClassInfo_HID_Device_t LED_HID_Interface =
{
    .Config =
        {
            .InterfaceNumber              = INTERFACE_ID_LED,
            .ReportINEndpoint             =
                {
                    .Address              = LED_EPADDR,
                    .Size                 = LED_EPSIZE,
                    .Banks                = 1,
                },
            .PrevReportINBuffer           = NULL,
            .PrevReportINBufferSize       = sizeof(LED_Report_t),
        },
};

static switch_t switches[SWITCH_COUNT];
static uint8_t switchesChanged = 1;

// Set to max already so we have our init flash
static uint16_t hidTimeout = HID_LED_TIMEOUT;

void RebootToBootloader(void) {
	/* Disconnect from the host - USB interface will be reset later along with the AVR */
	USB_Detach();

    // Back to the bootloader
    wdt_enable(WDTO_250MS);
    while(1);
}

/* This is verbose and annoying but the nice method wastes 30 bytes of RAM */
uint8_t load_switches(void) {
    uint8_t tmp;
    uint8_t result = 0;
    
#ifdef SOFT_LEDS
    tmp = PINB;
    LOAD_SWITCH(tmp, 1, result, 1); // PINB1, A
    LOAD_SWITCH(tmp, 0, result, 5); // PINB0, FX L
    tmp = PINC;
    LOAD_SWITCH(tmp, 2, result, 0); // PINC2, START
    LOAD_SWITCH(tmp, 1, result, 7); // PINC1, MACRO
#else
    tmp = PINB;
    LOAD_SWITCH(tmp, 6, result, 1); // PINB6, A
    LOAD_SWITCH(tmp, 5, result, 5); // PINB5, FX L
    LOAD_SWITCH(tmp, 4, result, 7); // PINB4, MACRO
    tmp = PINC;
    LOAD_SWITCH(tmp, 2, result, 0); // PINC2, START
#endif
    tmp = PIND;
    LOAD_SWITCH(tmp, 7, result, 2); // PIND7, B
    LOAD_SWITCH(tmp, 5, result, 3); // PIND5, C
    LOAD_SWITCH(tmp, 4, result, 4); // PIND4, D
    LOAD_SWITCH(tmp, 6, result, 6); // PIND6, FX R
    
    return result;
}

void update_switches(void) {
    uint8_t i, newState;
    uint8_t switchRead = load_switches();
    
    for(i = 0; i < SWITCH_COUNT; i++) {
        newState = switchRead & 1;
        if(!switches[i].debounce && newState != switches[i].lastReport) {
            switches[i].state = newState;
            switches[i].debounce = SWITCH_DEBOUNCE;
            switchesChanged = 1;
        }
        switchRead >>= 1;
    }
}

int main(void)
{
    GlobalInterruptDisable();
    
    InitConfig();
    
    SetupHardware();

    GlobalInterruptEnable();

    for (;;)
    {
        HID_Device_USBTask(&Inputs_HID_Interface);
        HID_Device_USBTask(&LED_HID_Interface);
        USB_USBTask();
        
        Endpoint_SelectEndpoint(CONFIG_OUT_EPADDR);
        if (Endpoint_IsOUTReceived()) {
            uint8_t ReceivedData[COMMAND_BYTES];
            Endpoint_Read_Stream_LE(ReceivedData, COMMAND_BYTES, NULL);
            Endpoint_ClearOUT();
            
            command_response_t respond = HandleConfig(ReceivedData);
            switch(respond) {
                // we are returning the requested data
                case RESPOND:
                    Endpoint_SelectEndpoint(CONFIG_IN_EPADDR);
                    Endpoint_Write_Stream_LE(ReceivedData, COMMAND_BYTES, NULL);
                    Endpoint_ClearIN();
                    break;
                case REBOOT:
                    RebootToBootloader();
                    break;
                // no data to return
                default:
                    break;
            }
        }
        
        if(updateLEDs && sdvxConfig.lightsOn) {
            updateLEDs = 0;
            if(!sdvxConfig.hidLights || hidTimeout >= HID_LED_TIMEOUT) {
                led_pattern_animate();
                if(sdvxConfig.keyLights) {
                    // Keep normal lights but override when we get flashes on BT or FX
                    // BT LEDs
                    for(uint8_t i = 1; i < 5; i++) {
                        if(switches[i].state) {
                            led_set_rgb(ledMap[i-1], &sdvxConfig.btColour);
                        }
                    }
                    // FX LEDs
                    for(uint8_t i = 5; i < 7; i++) {
                        if(switches[i].state) {
                            led_set_rgb(ledMap[i-1], &sdvxConfig.fxColour);
                        }
                    }
                    // START
                    if(switches[0].state) {
                        led_set_all_rgb(&sdvxConfig.startColour);
                    }
                }
            }
            // knob lights go above all
            if(sdvxConfig.knobLights)
                led_overlay_knobs();
            led_commit();
        } else if(!sdvxConfig.lightsOn) {
            led_set_all(0,0,0);
            led_commit();
        }
    }
}

/** Configures the board hardware and chip peripherals */
void SetupHardware()
{
    uint8_t i;
    /* Disable watchdog if enabled by bootloader/fuses */
    MCUSR &= ~_BV(WDRF);
    wdt_disable();
    
    for(i = 0; i < SWITCH_COUNT; i++) {
        switches[i].state = 0;
        switches[i].lastReport = 0;
        switches[i].debounce = 0;
    }
    // Inputs
    DDRB &= ~SWITCH_MASKB;
    DDRC &= ~SWITCH_MASKC;
    DDRD &= ~SWITCH_MASKD;
    // Pullups
    PORTB |= SWITCH_MASKB;
    PORTC |= SWITCH_MASKC;
#ifdef SOFT_LEDS
    PORTC &= ~_BV(1); // RESET has its own pullup
#endif
    PORTD |= SWITCH_MASKD;

    /* Hardware Initialization */
    encoder_init();
    led_init();
    led_pattern_init();
    
    USB_Init();
}

/** HID class driver callback function for the creation of HID reports to the host.
 *
 *  \param[in]     HIDInterfaceInfo  Pointer to the HID class interface configuration structure being referenced
 *  \param[in,out] ReportID    Report ID requested by the host if non-zero, otherwise callback should set to the generated report ID
 *  \param[in]     ReportType  Type of the report to create, either HID_REPORT_ITEM_In or HID_REPORT_ITEM_Feature
 *  \param[out]    ReportData  Pointer to a buffer where the created report should be stored
 *  \param[out]    ReportSize  Number of bytes written in the report (or zero if no report is to be sent)
 *
 *  \return Boolean \c true to force the sending of the report, \c false to let the library determine if it needs to be sent
 */
bool CALLBACK_HID_Device_CreateHIDReport(USB_ClassInfo_HID_Device_t* const HIDInterfaceInfo,
                                         uint8_t* const ReportID,
                                         const uint8_t ReportType,
                                         void* ReportData,
                                         uint16_t* const ReportSize)
{
    if(ReportType != HID_REPORT_ITEM_In || HIDInterfaceInfo != &Inputs_HID_Interface) {
        *ReportSize = 0;
        return false;
    }
    // nothing requested so let's make our own
    if(*ReportID == 0) {
        // Always runs because we can have KB macros even with joystick
        sendKeyboard ^= 1;
        if(sendKeyboard) {
            *ReportID = HID_REPORTID_KeyboardReport;
        } else {
            if(sdvxConfig.controlMode != CONTROL_KEYBOARD_MOUSE) {
                *ReportID = HID_REPORTID_JoystickReport;
            } else {
                *ReportID = HID_REPORTID_MouseReport;
            }
        }
    }
    
    if(*ReportID == HID_REPORTID_KeyboardReport) {
        Keyboard_Report_t* KeyboardReport = (Keyboard_Report_t*)ReportData;
        
        // Only the first 4 bytes are read by bemanitools, so let's use the first
        uint8_t macroUpdated = macro_make_report(&KeyboardReport->KeyCode[0]);
        
        if(!macroUpdated && (sdvxConfig.controlMode != CONTROL_KEYBOARD_MOUSE || !switchesChanged)) {
            *ReportSize = 0;
            return false;
        }
        
        if(sdvxConfig.controlMode == CONTROL_KEYBOARD_MOUSE) {
            // NOTE: using SWITCH_COUNT-1 so we don't write the report for the macro pin
            for(uint8_t i = 0; i < SWITCH_COUNT-1; i++) {
                // i+1 to take care of the shift from above
                KeyboardReport->KeyCode[i+1] = switches[i].state ? sdvxConfig.switches[i] : 0;
                switches[i].lastReport = switches[i].state;
            }
            switchesChanged = 0;
        }
        
        *ReportSize = sizeof(Keyboard_Report_t);
    } else {
        int8_t x = encoder_get(0);
        int8_t y = encoder_get(1);
        led_knobs_update(x, y);
        encoder_set(0, 0);
        encoder_set(1, 0);
        
        if(*ReportID == HID_REPORTID_MouseReport) {
            if(x == 0 && y == 0) {
                *ReportSize = 0;
                return false;
            }
            USB_MouseReport_Data_t* MouseReport = (USB_MouseReport_Data_t*)ReportData;
            
            MouseReport->X = x;
            MouseReport->Y = y;

            *ReportSize = sizeof(USB_MouseReport_Data_t);
        } else { // joystick
            if(x == 0 && y == 0 && !switchesChanged) {
                *ReportSize = 0;
                return false;
            }
            Joystick_Report_t* JoyReport = (Joystick_Report_t*)ReportData;
            
            joystickKnobs[0] += x;
            joystickKnobs[1] += y;
            for(uint8_t i = 0; i < 2; i++) {
                if(joystickKnobs[i] < 0)
                    joystickKnobs[i] += JOYSTICK_PPR;
                if(joystickKnobs[i] >= JOYSTICK_PPR)
                    joystickKnobs[i] -= JOYSTICK_PPR;
            }
            
            JoyReport->X = joystickKnobs[0];
            JoyReport->Y = joystickKnobs[1];
            
            // going backwards to make bitshifts nice
            for(int8_t i = SWITCH_COUNT-1; i >= 0; i--) {
                JoyReport->Buttons <<= 1;
                JoyReport->Buttons |= switches[i].state;
                switches[i].lastReport = switches[i].state;
            }
            switchesChanged = 0;
            
            *ReportSize = sizeof(Joystick_Report_t);
        }
    }
    return true;
}

/** HID class driver callback function for the processing of HID reports from the host.
 *
 *  \param[in] HIDInterfaceInfo  Pointer to the HID class interface configuration structure being referenced
 *  \param[in] ReportID    Report ID of the received report from the host
 *  \param[in] ReportType  The type of report that the host has sent, either HID_REPORT_ITEM_Out or HID_REPORT_ITEM_Feature
 *  \param[in] ReportData  Pointer to a buffer where the received report has been stored
 *  \param[in] ReportSize  Size in bytes of the received HID report
 */
void CALLBACK_HID_Device_ProcessHIDReport(USB_ClassInfo_HID_Device_t* const HIDInterfaceInfo,
                                          const uint8_t ReportID,
                                          const uint8_t ReportType,
                                          const void* ReportData,
                                          const uint16_t ReportSize) {
    if(HIDInterfaceInfo == &LED_HID_Interface && ReportType == HID_REPORT_ITEM_Out) {
        if(!sdvxConfig.hidLights)
            return;
        // reset our timeout
        hidTimeout = 0;
        
        LED_Report_t* LEDReport = (LED_Report_t*)ReportData;
#ifdef SOFT_LEDS
        // Load the user set colours as R/G/B instead of B/G/R
        for(uint8_t i = 0; i < LED_PHYSICAL_COUNT; ) {
            uint8_t offset = i+2;
            for(uint8_t j = 0; j < 3; j++) {
                leds[i++] = LEDReport->mainLights[offset--];
            }
        }
#else
        memcpy((uint8_t*)leds, LEDReport->mainLights, LED_PHYSICAL_COUNT);
#endif
        
        // Keep normal lights but override when we get flashes on BT or FX
        // BT LEDs
        for(uint8_t i = 0; i < 4; i++) {
            if(LEDReport->btFx[i]) {
                led_set_rgb(ledMap[i], &sdvxConfig.btColour);
            }
        }
        // FX LEDs
        for(uint8_t i = 4; i < 6; i++) {
            if(LEDReport->btFx[i]) {
                led_set_rgb(ledMap[i], &sdvxConfig.fxColour);
            }
        }
        if(LEDReport->btFx[6]) { // start
            led_set_all_rgb(&sdvxConfig.startColour);
        }
    }
}


/** Event handler for the library USB Connection event. */
void EVENT_USB_Device_Connect(void)
{
    
}

/** Event handler for the library USB Disconnection event. */
void EVENT_USB_Device_Disconnect(void)
{
    led_set_all(0,0,0);
    led_commit();
}

/** Event handler for the library USB Configuration Changed event. */
void EVENT_USB_Device_ConfigurationChanged(void)
{
    Endpoint_ConfigureEndpoint(CONFIG_OUT_EPADDR, EP_TYPE_BULK, CONFIG_EPSIZE, 1);
    Endpoint_ConfigureEndpoint(CONFIG_IN_EPADDR,  EP_TYPE_BULK, CONFIG_EPSIZE, 1);
    HID_Device_ConfigureEndpoints(&Inputs_HID_Interface);
    HID_Device_ConfigureEndpoints(&LED_HID_Interface);

    USB_Device_EnableSOFEvents();
}

/** Event handler for the library USB Control Request reception event. */
void EVENT_USB_Device_ControlRequest(void)
{
    USB_Process_BOS();
    HID_Device_ProcessControlRequest(&Inputs_HID_Interface);
    HID_Device_ProcessControlRequest(&LED_HID_Interface);
}

/** Event handler for the USB device Start Of Frame event. */
void EVENT_USB_Device_StartOfFrame(void)
{
    update_switches();
    macro_on_frame(&switches[SWITCH_COUNT-1]);
    HID_Device_MillisecondElapsed(&Inputs_HID_Interface);
    HID_Device_MillisecondElapsed(&LED_HID_Interface);
    
    if(hidTimeout < HID_LED_TIMEOUT) {
        hidTimeout++;
    }
    
    // we use a sentinel since this is actually inside an interrupt!
    // less LED flicker if ran outside
    if(led_on_frame()) {
        updateLEDs = 1;
    }
    
    for(int i = 0; i < SWITCH_COUNT; i++) {
        if(switches[i].debounce) {
            switches[i].debounce--;
        }
    }
}

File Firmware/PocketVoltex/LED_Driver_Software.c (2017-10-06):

#define GND_COUNT 4
// RGB * 2
#define LED_PINS 6

// LED gnd 0-3 are on PC7-4
#define GND_PORT PORTC
#define GND_DDR  DDRC
#define GND_MASK 0xF0
#define GND_OFFSET 4 // in bits

// LED power BGR BGR PB2-7
#define LED_PORT PORTB
#define LED_DDR  DDRB
#define LED_MASK (0b111111 << 2)

// How many are actually PWM'd, because the chip isn't that quick
// MUST be a multiple of BRIGHTNESS_LEVELS
#define BRIGHTNESS_DOWNSCALE 128
#define BRIGHTNESS_INCREMENT (BRIGHTNESS_LEVELS / BRIGHTNESS_DOWNSCALE)

#define UPDATE_HZ 100
// prescaler is the div8
#define TIMER_COMPARE ((F_CPU / 8 / UPDATE_HZ / GND_COUNT / BRIGHTNESS_DOWNSCALE)-1)
#if TIMER_COMPARE > 255
    #error timer compare too large for timer register
#endif

#define R 2
#define G 1
#define B 0

static volatile uint8_t leds_frontbuffer[LED_PHYSICAL_COUNT];

void led_init(void) {
    // all GNDs low level for high impedence or gnd
    GND_PORT &= ~GND_MASK;
    // all GNDs input
    GND_DDR &= ~GND_MASK;
    
    // all LEDs off
    LED_PORT &= ~LED_MASK;
    // all LEDs output
    LED_DDR |= LED_MASK;
    
    memset(leds, 0, LED_PHYSICAL_COUNT);
    memset((uint8_t*)leds_frontbuffer, 0, LED_PHYSICAL_COUNT);
    
    // 64 light levels * 60Hz update * 4 different GND pins = 15360Hz
    // 520 clock cycles for our interrupt handler
    // CTC mode
    TCCR0A = _BV(WGM01);
    // clk/8 prescaler
    TCCR0B = _BV(CS01);
    OCR0A = TIMER_COMPARE;
    // Enable interrupt on OCR0A
    TIMSK0 = _BV(OCIE0A);
    // Clear interrupt
    TIFR0 = _BV(OCF0A);
}

void led_commit(void) {
    memcpy((uint8_t*)leds_frontbuffer, leds, LED_PHYSICAL_COUNT);
}

/* Straight voodoo magic, consult the Inline Assembler Cookbook
   Equivalent to:
   if(*led++ > brightness)
       out |= _BV(outPin)
*/
#define LED_PIN_SET(led, outPin)                            \
    __asm__ volatile(                                       \
        "ld __tmp_reg__, %a["#led"]+                    \n\t\
         cp %[bright], __tmp_reg__                      \n\t\
         brcc skip%=                                    \n\t\
         ori %[out], (1 << "#outPin")                   \n\t\
         skip%=:"                                           \
        : [out] "+a" (out), [led] "+z" (led) /* outputs */  \
        : [bright] "r" (brightness)          /* inputs */ )

// This function once took about 279 clock cycles.
// Optimised GND accesses got it to 157
// Optimised variables to static, got it to 100
// Made LED setter assembly, got it to 90
ISR(TIMER0_COMPA_vect) {
    /* Why are these static here instead of at the top of file?
       The compiler won't optimise 2 consecutive operations to use a register,
       and instead will perform a costly lds-sts every time. Making them
       static here will cache them in a local register.
    */
    // Because we roll over on each loop and want to start at 0 this starts at max
    static uint8_t currentGnd = GND_COUNT - 1;
    // This saves us doing a costly dynamic _BV()
    static uint8_t currentGndMask = 0;
    static uint8_t brightness = BRIGHTNESS_LEVELS - BRIGHTNESS_INCREMENT;
    static volatile uint8_t* offset = &leds_frontbuffer[0];
    
    uint8_t out = 0;
    
    currentGnd++;
    currentGndMask >>= 1;
    if(currentGnd >= GND_COUNT) {
        currentGnd = 0;
        // Because we work backwards start at the high end and shift down
        currentGndMask = _BV(7);
        offset = &leds_frontbuffer[0];
        brightness += BRIGHTNESS_INCREMENT;
        // brightness rolls over cleanly due to being a multiple
        #if BRIGHTNESS_LEVELS != 256
        if(brightness > BRIGHTNESS_MAX)
            brightness = 0;
        #endif
    }

    // Faster than loops
    // NOTE: ASM MACRO INCREMENTS OFFSET
    LED_PIN_SET(offset, 2);
    LED_PIN_SET(offset, 3);
    LED_PIN_SET(offset, 4);
    LED_PIN_SET(offset, 5);
    LED_PIN_SET(offset, 6);
    LED_PIN_SET(offset, 7);
    
    // Turn off before switch
    LED_PORT &= ~LED_MASK;
    // Enable new ground
    GND_DDR = (GND_DDR & ~GND_MASK) | currentGndMask;
    LED_PORT |= out;
}

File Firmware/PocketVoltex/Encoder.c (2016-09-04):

#include "Encoder.h"

// SDVX Controller - PD0-3
#define ENCODER_COUNT 2

#define ENCODER_PORT PORTD
#define ENCODER_PIN  PIND
#define ENCODER_DDR  DDRD

#define GET_ENCODER_0() (ENCODER_PIN & 0b11)
#define GET_ENCODER_1() ((ENCODER_PIN >> 2) & 0b11)

typedef struct {
    int8_t position;
    uint8_t state;
} encoder_t;

static volatile encoder_t encoders[ENCODER_COUNT] = {};

void encoder_init(void) {
    // inputs
    ENCODER_DDR &= ~0x0F;
    // pullups
    ENCODER_PORT |= 0x0F;
    
    encoders[0].state = GET_ENCODER_0();
    encoders[1].state = GET_ENCODER_1();
    
    // Edge interrupts on all INT pins
    EICRA = _BV(ISC30) | _BV(ISC20) | _BV(ISC10) | _BV(ISC00);
    // Enable the interrupts
    EIMSK = _BV(INT3) | _BV(INT2) | _BV(INT1) | _BV(INT0);
    // Clear interrupt flags
    EIFR  = _BV(INTF3) | _BV(INTF2) | _BV(INTF1) | _BV(INTF0);
}

int8_t encoder_get(uint8_t num) {
    return encoders[num].position;
}

void encoder_set(uint8_t num, int8_t val) {
    encoders[num].position = val;
}

// Adapted from the wonderful Encoder.h by PJRC
void update(uint8_t num, uint8_t newState) {
    int8_t position = encoders[num].position;
    uint8_t state = encoders[num].state | (newState << 2);
    encoders[num].state = newState;
    switch (state) {
        case 1: case 7: case 8: case 14:
            if(position < 127)
                encoders[num].position++;
            return;
        case 2: case 4: case 11: case 13:
            if(position > -128)
                encoders[num].position--;
            return;
        case 3: case 12:
            if(position < 125)
                encoders[num].position += 2;
            return;
        case 6: case 9:
            if(position > -126)
                encoders[num].position -= 2;
            return;
    }
    
}
    
ISR(INT0_vect) { update(0, GET_ENCODER_0()); }
ISR(INT1_vect) { update(0, GET_ENCODER_0()); }
ISR(INT2_vect) { update(1, GET_ENCODER_1()); }
ISR(INT3_vect) { update(1, GET_ENCODER_1()); }

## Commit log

2016-09-19 Nuke switch LEDs, widen board. WIP
    [SDVX_Mini.PcbDoc, SDVX_Mini.SchDoc]
2016-10-25 Wide board complete
    [SDVX_Mini.PrjPCB, SDVX_Mini.SchDoc, other_bom.csv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]
2016-10-26 V2 stuff done, initial LED support
    [other_bom.csv]
2016-10-26 LEDs code now 300% faster
2016-10-28 broke LED descriptor
2016-10-29 Working LEDs
2016-11-11 Case and new encoders
    [BOARD_SHAPE.dxf, RING_BOT_SUPPORTS.dxf, RING_TOP_SUPPORTS.dxf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]
2016-11-22 16MHz, better holes, bigger board, proper microswitch
    [SDVX_Mini.SchDoc, other_bom.csv]
2016-11-23 Gerber v3
    [SDVX_Mini.PrjPCB]
2016-12-11 LED patterns, minor improvements
2016-12-16 New board
2017-01-08 Add macro key on reset switch
2017-01-08 Minor cleanups
    [bom_sdvx.csv, seeed_bom.csv]
2017-01-08 Rev4 PCB - no LED holes, fixed tenting, slightly bigger encoder holes
    [SDVX_Mini.PrjPCB, SDVX_Mini.SchDoc]
2017-01-08 Case improvements
    [BOARD_SHAPE.dxf, RING_BOT_SUPPORTS.dxf, RING_TOP_SUPPORTS.dxf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]
2017-01-08 Better encoders (again), better PCB art
2017-01-08 Stronger case
    [case.scad]
2017-01-08 Better case, nicer art
    [Artwork.dxf, art_trimmed.scad, bottom_plate.scad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]
2017-01-08 More knob stability, better lineweights, better switch pos, switch label, smarter hole placement
    [BOARD_SHAPE.dxf, SDVX_Mini.SchDoc]
2017-01-08 Minor cleanup
    [case.scad]
2017-01-09 Move L1, L2, new resonator, new LED resistors
    [SDVX_Mini.PrjPCB, SDVX_Mini.SchDoc, bom_sdvx.csv]
2017-01-09 Production commit :)
    [SDVX_Mini.PrjPCB, SDVX_Mini.SchDoc]
2017-01-18 Update art and case art to fit within 1mm boundary case to be pretty
    [Artwork.dxf, BOARD_SHAPE.dxf, PEC16.stl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]
2017-02-01 Fix libusb connectivity and add more config stuff
    [Descriptors.h, PocketVoltex.c]
2017-02-09 Fix config comunication 🙏
    Turns out using 6 endpoints when you only support 5 is a recipe for disaster
    [Descriptors.h, PocketVoltex.c]
2017-02-09 Slight RAM saving in LED patterns by using a union
2017-02-09 LEDs now high resolution internally and RGB for user, and knobs are stuck on the sides
    [LED.h, LEDPatterns.h, PocketVoltex.c]
2017-02-09 Much improved LEDs and persistant knob LEDs
2017-02-15 Add joystick interface, fix STALL bugs maybe
    [Descriptors.h, PocketVoltex.c]
2017-02-16 1 STALL fixed, 1 to go
    [PocketVoltex.c]
2017-02-16 Actually, properly fix stalls
    [Descriptors.h]
2017-02-16 Fix inline ASM for GCC 4.9
    [LED.h]
2017-02-17 Breathe mode, LED cleanup and brightness levels increase
2017-03-04 Case adjustments
    [Artwork.dxf, bottom_plate.scad, bottom_ring.scad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]
2017-03-04 Add forgotten bootloader files
    [fader.xlsx]
2017-03-15 Much more case material, may revert if it doesn't fix clack
    [bottom_ring.scad, case.scad]
2017-05-20 Better LED patterns
2017-05-21 Fix eeprom freeze, LED flash, Macro in config
2017-06-14 LED soldering clarification
2017-07-21 Prototype for rev5
    [SDVX_Mini.PrjPCB, SDVX_Mini.SchDoc, bom_sdvx.csv]
2017-08-30 Prototype for rev 6
    [SDVX_Mini.PrjPCB, SDVX_Mini.SchDoc, bom_sdvx.csv]
2017-10-06 Much improvement case build process
    [Artwork.dxf, RING_BOT_SUPPORTS.dxf, RING_TOP_SUPPORTS.dxf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]
2017-10-06 Firmware support for rev5 LEDs
2017-10-06 Forgot to add new LED driver files
2017-10-06 Rev6 case updates
    [Artwork.dxf, case.scad]
2018-01-25 DIY docs rev6, firmware tweaks, software tweaks
    [art_rev6.DXF, box.scad, case.scad]
2018-05-13 Dimensions cleanup in prep
    [board_dimensions.scad, board_shape.scad, case.scad]
2018-07-07 Fix LED strings
2018-10-29 rev7 - Kicad!
    [Artwork.dxf, BOARD_SHAPE.dxf, KSC521J.stl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]
2018-10-29 Add firmware defaults reset, start button LEDs, overall brightness (rev6+)
    [LED.h, LED_Driver_SK9822.c, PocketVoltex.c]
2019-07-07 Kicad 5.1, USB 2.0 C receptacle, CC pulldown
    [PocketVoltex.kicad_pcb, PocketVoltex.sch]
2019-07-07 Change rev to 8
    [PocketVoltex.kicad_pcb, PocketVoltex.sch]
2020-10-28 Commit all the in-progress stuff for a clean slate
    [PEC16.stl, PocketVoltex.kicad_pcb, PocketVoltex.sch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]
